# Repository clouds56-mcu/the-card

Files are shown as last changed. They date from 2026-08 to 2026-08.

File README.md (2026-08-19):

# The Card — E-Paper Smart Badge



**Website:** <https://clouds56-mcu.github.io/the-card/>

> An **ESP32-S3** based DIY/learning smart badge: e-paper wallpapers, Bluetooth, NFC, multi-button watch-style control, and on-board sensors, worn around the neck like an ID badge.

## 📋 Project Brief

| Item | Spec |
|---|---|
| **Positioning** | DIY / open learning platform (open-source, flashable, well-documented) |
| **MCU** | ESP32-S3-WROOM-1-N16R8 (16 MB Flash + 8 MB Octal PSRAM) |
| **Display** | 2.9" e-paper 296×128 (SSD1680, partial refresh / 4-gray) |
| **Wireless** | Bluetooth 5 LE (on-module) + NFC (ST25DV04KC dynamic tag, etched v0.2 antenna) |
| **Input** | 4× tactile buttons (up/down/select/menu, watch-style) |
| **Sensors** | 6-axis IMU (LSM6DSO) + Temp/Humidity (SHT40) |
| **Power** | 3.7 V Li-Po + USB-C charging + fuel gauge |
| **Wear** | Lanyard badge form factor |

## 📚 Documentation Index

| Doc | Description |
|---|---|
| [docs/architecture.md](docs/architecture.md) | System block diagram, subsystem design, **GPIO pin map** |
| [docs/bom.md](docs/bom.md) | Full BOM (with LCSC part #s / unit prices / links) + cost analysis |
| [docs/power-budget.md](docs/power-budget.md) | State-based power model + battery-life scenarios |
| [website/README.md](website/README.md) | Product site, hardware previews, and candidate release downloads |

## 💰 Key Takeaways

- **Component BOM (incl. panel + battery, excl. PCB/case):** ~$29 (1-off) / ~$21 (@100) / ~$18 (@1k)
- **Landed cost (incl. PCBA + case + assembly):** ~$40 (1-off) / ~$28 (@100) / ~$21 (@1k)
- **Cost driver:** e-paper panel (~$7, 33%) + MCU (~$4, 18%) + battery/IMU (~$2.5 each)
- **Battery life:** ~5.4 months theoretical for modeled daily use (1000 mAh), with ~4–5 months as a planning range; prototype measurement is pending
- **#1 power gotcha:** keep the WS2812 gated; the always-enabled SO-8 ST25DV and ME6211 dominate the revised ~0.16–0.17 mA sleep estimate

## 🚧 Optional Expansion (not in core BOM)

- Microphone (INMP441 / MSM261S) — voice interaction
- Ambient light (BH1750) — auto contrast
- Solar harvesting (paired with ST25DV's EH pin)
- Color e-paper (2.66" R/Y/B/W, slow 11 s refresh)

---

## 📄 License

This project is released under the **[MIT License](LICENSE)** — firmware, hardware designs, and documentation alike. Build it, modify it, ship it.

---

*Prices reflect 2026-08 LCSC / JLCPCB / Good Display market data and are for reference only — confirm at order time.*

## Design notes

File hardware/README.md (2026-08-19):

# hardware/ — Schematic & PCB (KiCad, code-first)

The electrical design of **the-card**, captured in code and emitted as both a
KiCad **schematic** (`.kicad_sch`) and a **netlist** (`.net`). KiCad 10 is
installed; the schematic opens in eeschema and is ERC-clean (0 errors).

```
hardware/
├── parts.yaml              # parts/procurement manifest, kept in sync with circuit.py
├── design_metadata.py      # sole project/design SemVer identity
├── pyproject.toml + uv.lock# uv project: skidl + easyeda2kicad (+ pypdf dev)
├── circuit.py              # the design in SKiDL (connectivity) -> the-card.net
├── gen_hierarchical_schematic.py # current deterministic A2 layout generator
├── gen_pcb.py              # deterministic placement, routing, planes, and keepouts
├── pcb_router.py           # board-specific fanout and deterministic maze routing
├── nfc_antenna.py          # v0.2 coil geometry and first-order RF model
├── verify_schematic.py     # compare every KiCad pin's peers with circuit.py
├── gen_schematic.py        # legacy flat-layout generator; not used currently
├── the-card.kicad_pro      # KiCad 10 project
├── the-card.kicad_sch      # GENERATED single-page A2 schematic
├── the-card.kicad_pcb      # GENERATED four-layer PCB layout
├── the-card.kicad_dru      # project DRC rules, including the NFC quiet area
├── sym-lib-table / fp-lib-table  # register our the-card + passives libraries
├── SCHEMATIC-GUIDE.md      # functional-region drawing and review notes
├── datasheets/             # archived datasheet PDFs + index
├── scripts/fetch_libs.sh   # regenerate libraries/ from LCSC#s in parts.yaml
├── scripts/normalize_libraries.py # reviewed corrections to fetched footprints
├── scripts/release_fabrication.py # checked Gerber/drill/BOM/placement release
├── scripts/export_design_review.py # portable CI schematic/PCB review exports
├── scripts/release_manifest.py # versioned release.json metadata + hashes
├── scripts/rasterize_svg.py # review PNGs from KiCad SVG plots
└── libraries/              # Reviewed 2D libs tracked; generated 3D models ignored
```

## One-time setup

```bash
cd hardware
uv sync                     # create .venv, install skidl + easyeda2kicad
./scripts/fetch_libs.sh     # fetch symbol/footprint/3D for every LCSC part
```

## Generate and verify

```bash
uv run python circuit.py
uv run python gen_hierarchical_schematic.py
uv run python verify_schematic.py
kicad-cli sch erc --severity-all --output /tmp/erc.json --format json the-card.kicad_sch
```

The verifier exports the complete KiCad schematic and compares both the peer
set of every component pin and every explicitly named net with the canonicalized
SKiDL circuit. The expected v0.2.0 result is 78 components and 292 component
pins with identical connectivity across 43 canonical named nets. KiCad ERC has 0
violations.

Generate the PCB layout with KiCad's bundled Python:

```bash
/Applications/KiCad/KiCad.app/Contents/Frameworks/\
Python.framework/Versions/3.9/bin/python3 gen_pcb.py
kicad-cli pcb drc --output /tmp/pcb-drc.json --format json the-card.kicad_pcb
```

The board is a portrait ID-1 outline (53.98 × 85.60 mm), four layers, and
0.8 mm thick. The display and controls are on the front; the ESP32, battery,
sensors, power circuitry, USB-C, and display connector are on the rear. The
generator encodes display, 603048 battery, ESP32 antenna, and NFC keepouts. The
NFC coil occupies a dedicated all-copper-layer RF quiet area: only `NFC_AC0`
and `NFC_AC1` antenna copper is allowed there, with no ground or power plane
beneath it. F.Cu and B.Cu carry local signals over ground pours, In1.Cu is the
primary ground plane, and In2.Cu is the primary 3V3 plane plus longer signal
routes. Ground stitching ties the pours together. The generated board is fully
routed and passes KiCad DRC with 0 violations and 0 unconnected items. Four
non-fabrication reference images are embedded beside the board in PCB Editor,
showing F.Cu, In1.Cu, In2.Cu, and B.Cu simultaneously without affecting plots.

## CI design review

For every CI run, `.github/workflows/ci.yml` publishes a short-lived
`design-review-<commit>` artifact after ERC and DRC pass. It contains the
schematic as PDF/SVG/PNG, a thumbnail, a multipage PCB PDF, and front, inner,
and mirrored back PCB PNGs. These files make schematic and layout changes easy
to inspect without KiCad; they are previews from one commit, not approved
fabrication outputs. The separate `kicad-reports` artifact retains the ERC and
DRC JSON reports, including reports from failed runs when available.

Run the manual `Hardware output` workflow when a complete candidate handoff is
needed. It rebuilds all release gates in the pinned KiCad environment and
uploads the fabrication, preview, assembly, reports, manifest, and checksums as
one 30-day Actions artifact. The workflow does not publish a GitHub Release or
mark the physical approval gates complete.

Build a manufacturing handoff into a new directory after generation:

```bash
uv run python scripts/release_fabrication.py \
  --output ../outputs/the-card-hardware-v0.2.0
```

`DESIGN_VERSION` in `design_metadata.py` is the sole maintained identity. It is
written in full to both KiCad title blocks and release metadata; the constrained
PCB silkscreen derives the matching major/minor mark (`HW 0.2`). Before 1.0, a
physical/electrical/mechanical PCB change advances the minor version, while an
artifact-only correction may advance the patch version. Never overwrite an
already published version. The first physically validated design can become
v1.0.0. The earlier v0.1.0 draft is retained only in Git history because it was
never ordered and contains the NFC issue corrected in v0.2.0.

The release command refuses to overwrite an existing directory or use a dirty
worktree. It runs the connectivity and canonical-net-name verifier, then
requires a clean full DRC, schematic parity check, and ERC. The output tree is:

```text
fabrication/       # Gerbers, PTH/NPTH drills, notes, fabrication-only ZIP
preview/           # schematic/PCB PDFs and PNGs, layer/drill plots, preview ZIP
assembly/
├── canonical/     # normalized BOM/placement CSV+JSON and assembly drawings
└── jlcpcb/        # upload-ready BOM and position CSVs
reports/           # ERC, DRC/parity, and drill reports
release.json       # release identity, provenance, validation, pending approval
SHA256SUMS         # hashes for every artifact and release.json
```

Pass `--include-3d` only when all ignored supplier 3D models referenced by the
board are present and reviewed. Without it, the release remains complete for
fabrication and assembly and uses 2D previews generated from tracked design
files. The internal assembly BOM reports unresolved sourcing explicitly; a
clean board does not imply that every row is ready for a turnkey PCBA order. See
[`FABRICATION.md`](FABRICATION.md) before sending any files to a board house.

`assembly/jlcpcb/bom.csv` follows JLC's eight-column
`Comment, Description, Designator, Footprint, LibRef, Pins, Quantity, JLCPCB Part #`
format. Exact LCSC/JLC codes are written to `JLCPCB Part #` when assigned.
`assembly/jlcpcb/positions.csv` is the matching millimetre CPL with
`Designator, Mid X, Mid Y, Rotation, Layer` and normalized `Top`/`Bottom`
layer names.

Open the schematic:
```bash
/Applications/KiCad/KiCad.app/Contents/MacOS/eeschema the-card.kicad_sch
```

> `gen_hierarchical_schematic.py` is retained under its original filename, but it
> now emits one A2 sheet. It overwrites `the-card.kicad_sch`; put durable layout
> changes into its placement and region-offset tables so regeneration stays
> deterministic. `gen_schematic.py` is the previous flat A1 generator and is
> retained only as a reference.

## How it fits together

`parts.yaml` holds procurement and part data. Its `lcsc_parts` section drives
EasyEDA library fetching, while `assembly_parts` records exact BOM selections
that reuse existing project or KiCad symbols and footprints. An
`assembly_parts` entry with the same reference as an `lcsc_parts` entry
overrides only the procurement selection, allowing a verified pin-compatible
replacement to keep the existing symbol and footprint. `fetch_libs.sh`
builds the two KiCad libraries, while `circuit.py` defines electrical
connectivity and emits `the-card.net`. The layout generator imports that circuit
and changes only its presentation: one A2 page containing Power/USB, MCU,
NFC/sensors, e-paper, and UI
regions. For an electrical change, update `circuit.py`, regenerate the netlist and
schematic, then run `verify_schematic.py` before accepting the result. See
[`FABRICATION.md`](FABRICATION.md) for stackup, ordering, and assembly checks.

Every resistor and capacitor also receives hidden `Related To` and `Function`
properties from `circuit.py`. The single-page schematic shows compact functional
callouts, while KiCad properties and the internal assembly BOM retain the exact
per-reference annotations without crowding the drawing. The layout keeps support
passives beside their related blocks and emits explicit dots at true wire
junctions; visually crossing wires without a dot are not connected.

## Verification status (done)

The originally flagged sections were checked against datasheets (see
`../PROGRESS.md` §7 and the full pinout cross-check). The bare panel's required
SSD1680 booster, 25 V pump capacitors, and 50 V rail bypass network are now
present on the host PCB. Residual
PCB-layout items are:

- **ST25DV04KC antenna** — design v0.2.0 uses a nine-turn, 0.20 mm F.Cu spiral in the
  front-left strip, with a dedicated quiet area on all four copper layers. The
  ST square-equivalent heuristic gives about 4.52 µH; an NXP rectangular-coil
  cross-check brackets about 3.19–3.98 µH and implies roughly 6.1–14.7 pF of
  nominal added capacitance before stray/assembly loading. C29 therefore accepts
  0–22 pF C0G/NP0, but remains unpopulated until measurement. Verify resonance,
  Q, and multi-phone read/write range in the final enclosure; treat more than
  about 15–18 pF, poor Q, or inadequate range as an antenna-respin signal.
- **Display FPC** — J2 is now the verified single-row Hirose
  FH12-24S-0.5SH(55): 24 positions, 0.5 mm pitch, bottom contact, for a 0.30 mm
  FPC. The project footprint numbers its two hold-down tabs 25 and 26 so both
  are tied to ground by the schematic. Rear silkscreen marks pin 1; confirm the
  folded panel orientation with a paper or physical mock-up before ordering.
- **JST-PH battery polarity** — rear silkscreen marks `BAT+` and `BAT-`, but the
  selected pack's cable must still be verified before plugging it in.

The DW01A/HXY 8205A protection stage has been checked against both datasheets:
R9=100 Ω, R10=1 kΩ, DOUT drives G1 on the cell-negative side, and COUT drives
G2 on the pack-negative side.

## Gotchas

- **easyeda2kicad 1.0.1:** `--output` must be **absolute** with
  `--project-relative` (relative paths crash). `fetch_libs.sh` handles this.
- **EasyEDA API 403:** rate-limits after a big batch — re-run in a few minutes.
- **SKiDL reports pin Y inverted** vs KiCad (math y-up vs KiCad y-down); the
  layout generator handles KiCad's screen-coordinate rotations explicitly.
- **ESP32-S3-WROOM-1-N16R8** uses GPIO33–37 for its Octal PSRAM;
  `circuit.py` leaves GPIO35–37 unconnected and uses GPIO16 for `EPD_PWR_EN`.
- The ST25DV SO-8 GPO is open-drain. Design v0.2.0 adds its required 10 kΩ pull-up R17
  and routes `NFC_IRQ` to GPIO21; GPIO3 is deliberately unused because it is a
  strap-sensitive pin.
- The generator sets embedded part pins to `passive` because several EasyEDA
  symbols have incorrect electrical types. `verify_schematic.py` independently
  checks actual connectivity rather than relying on those types.

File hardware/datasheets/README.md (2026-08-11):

# Datasheets

Reference manuals for the-card's components — **all archived locally as PDF** so
the design is reviewable offline and survives link-rot. PDFs are committed on
purpose: manufacturer pages and URLs change or disappear, and for a hardware
project an archived datasheet is part of the design record.

## Local archive

| Ref | Part | LCSC | File | Source |
|---|---|---|---|---|
| U1 | ESP32-S3-WROOM-1 (module) | C2913202 | `ESP32-S3-WROOM-1_Espressif.pdf` | Espressif |
| U1 | ESP32-S3 (chip) | — | `ESP32-S3_Espressif.pdf` | Espressif |
| U2 | ST25DV04KC | C5221752 | `ST25DV04KC_ST.pdf` | ST (Farnell mirror) |
| U3 | LSM6DSO | C2655100 | `LSM6DSO_ST.pdf` | ST (LCSC) |
| U4 | SHT40 | C7461849 | `SHT40_Sensirion.pdf` | Sensirion (SparkFun CDN) |
| U5 | MAX17048 | C2682616 | `MAX17048_Maxim.pdf` | Maxim/ADI (LCSC) |
| U6 | TP4056 | C382139 | `TP4056.pdf` | TPOWER (LCSC wmsc) |
| U7 | DW01A | C18164398 | `DW01A_Fortune.pdf` | Fortune Semiconductor |
| U8 | HXY 8205A | C5148694 | [HXY datasheet](https://www.lcsc.com/datasheet/C5148694.pdf); `FS8205A_Fortune.pdf` is the pin-compatible symbol-template reference | HXY MOSFET / Fortune Semiconductor |
| U9 | ME6211C33 | C82942 | `ME6211_Microne.pdf` | MICRONE (LCSC) |
| U10 | USBLC6-2SC6 | C7519 | `USBLC6-2_ST.pdf` | ST (LCSC) |
| Q1, Q2 | SI2301 | C10487 | `SI2301_Vishay.pdf` | Vishay (LCSC) |
| D1 | WS2812B-Mini | C527089 | `WS2812B-Mini_Worldsemi.pdf` | Worldsemi (LCSC) |
| J1 | TYPE-C-31-M-12 | C165948 | `TYPE-C-31-M-12.pdf` | LCSC |
| SW1–4 | TS-1187A | C318884 | `TS-1187A.pdf` | LCSC |
| J2 / panel | GDEY029T94 | — (distributor) | `GDEY029T94_GoodDisplay.pdf` + `GDEY029T94_extracted.md` | Good Display |
| — | SSD1680 (e-ink driver IC) | — | `SSD1680_SolomonSystech.pdf` | Solomon Systech |

LCSC product page pattern: `https://www.lcsc.com/product-detail/C<LCSC>.html`

## Notes

- `st.com` and `espressif.com` block scripted downloads, so those were fetched
  via mirrors (LCSC, Farnell, DigiKey, SparkFun/Adafruit CDNs) that allow it.
- The GDEY029T94 has a text extraction (`GDEY029T94_extracted.md`) for quick
  grep of the pin table — the §5 pin assignment was used to verify `circuit.py`.
- Battery (3.7 V 1000 mAh, 603048) and lanyard hardware have no part datasheet.
- **Re-verify the revision before tape-out.** Datasheets get reissued (e.g.
  GDEY029T94 `24.10.22`) and pinouts/footprints can shift between revs.

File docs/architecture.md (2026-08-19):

# System Architecture

## 1. Block Diagram

```
                           ┌─────────────────────────────────────────────┐
                           │              ESP32-S3-WROOM-1-N16R8         │
                           │  (Dual-core 240MHz · 16MB Flash · 8MB PSRAM)│
                           │                                             │
   USB-C ──┬─ ESD ── D+/D-─┤  USB-Serial-JTAG (native USB, no CH340)     │
   5V  ────┤               │                                             │
           │               │  SPI  ──► [E-ink SSD1680 2.9" 296×128]       │
   TP4056 ◄─┘ charge        │  I2C0 ─► { ST25DV04KC · LSM6DSO · SHT40     │
   DW01+MOS ◄─ protection   │             · MAX17048 }                    │
           │                │  GPIO ► 4× Tactile Buttons (deep-sleep wake)│
   Li-ion 3.7V              │  GPIO ─► WS2812 RGB (via MOSFET power gate)│
   1000mAh ─┬─ LDO 3.3V ───►│                                             │
           │                │  IRQ  ◄─ NFC GPO / IMU INT                  │
           └────────────────┤  ADC  ◄─ VBATT divider (MAX17048 primary)   │
                            └─────────────────────────────────────────────┘
```

## 2. Subsystem Design

### 2.1 MCU — why ESP32-S3

| Candidate | Trade-off | Verdict |
|---|---|---|
| **ESP32-S3-WROOM-1-N16R8** ✅ | 16 MB Flash for OTA and assets + 8 MB Octal PSRAM for image/UI headroom, native USB, strong availability | **Selected** |
| N8R2 (8 MB Flash, 2 MB Quad PSRAM) | Sufficient for the current framebuffer, but offers less OTA/image headroom without a consistent sourcing advantage | Alt (minimum memory) |
| N4 (4 MB, no PSRAM) | Frame buffer squeezes SRAM, large-image refresh struggles | Alt (max savings) |
| S3-MINI-1 | Smaller but dense routing, less DIY-friendly | No |
| Bare die S3FN8 | Requires own RF + Flash routing, not for a learning platform | No |

- **N16R8 over N8R2:** the footprint is identical, current sourcing is at least
  as strong, and the extra memory simplifies dual-slot OTA, image decoding,
  fonts, and future UI work. Firmware must select 16 MB Quad flash and 8 MB
  Octal PSRAM.
- N16R8's recommended ambient range is −40 to +65 °C, versus +85 °C for N8R2;
  +65 °C is acceptable for this consumer wearable, but not an industrial-hot
  environment.
- On-module PCB antenna → **no RF design required**, DIY-friendly.

### 2.2 Display Subsystem

- **Main panel:** 2.9" 296×128 monochrome e-paper (GDEY029T94, SSD1680 controller)
  - 4-wire SPI, supports **partial refresh 0.3 s / full refresh 1.5 s** / 4-gray
  - Bistable: **zero power for a static image** — the core of badge battery life
  - Outline 79×36.7 mm — exactly standard badge aspect ratio
- Routing: 24-pin 0.5 mm FPC flip connector for easy panel swap
- Host support: 47 µH SSD1680 boost stage, 30 V MOSFET/Schottky diodes, and
  25 V-rated pump/HV bypass capacitors per the panel reference design
- **Note:** SSD1680 has no power-enable pin; Q2 cuts the panel VCI/booster input

### 2.3 Wireless Subsystem

| Channel | Chip | Role |
|---|---|---|
| Bluetooth 5 LE | ESP32-S3 on-module | Phone app pushes wallpapers, config, OTA |
| NFC 13.56 MHz | **ST25DV04KC** (4 Kbit dynamic tag) | Phone tap reads badge info / vCard / URL; MCU rewrites tag content anytime over I2C |

**Why ST25DV04KC over NXP NTAG I2C Plus:**
- ✅ Dynamic tag memory can be updated by the MCU over I²C
- ✅ **GPO wake pin:** phone proximity triggers an MCU interrupt (enables "tap to check-in")
- ✅ Cheaper (~$0.44 @100 vs NT3H2211 ~$0.7)
- ⚠️ Type 5 (ISO15693); modern phones support NDEF fine; only very old devices are slightly less compatible than Type 2

The IC supports energy harvesting, but `V_EH` is intentionally left unconnected
in the current design to keep the power architecture simple.

Design v0.2.0 connects the ST25DV's open-drain GPO through mandatory 10 kΩ pull-up R17
to `NFC_IRQ` on RTC-capable GPIO21; GPIO3 is no longer used because it is a
strap-sensitive pin. The antenna uses distinct `NFC_AC0`/`NFC_AC1` nets, a
nine-turn 0.20 mm F.Cu etched coil (L2), and an all-four-copper-layer RF quiet
area. DNP C29 accepts 0–22 pF C0G/NP0 only after measurement shows how far the
assembled antenna sits above 13.56 MHz. Parallel capacitance can lower a high
resonance, but it cannot correct an antenna that already resonates below the
target.

### 2.4 Sensor Subsystem

| Sensor | Model | Purpose | Low power |
|---|---|---|---|
| 6-axis IMU | **LSM6DSO** | Flip-to-wake, step count, raise-to-wake, gestures | LP 0.012 mA |
| Temp/Humidity | **SHT40** | Environment (shown in a screen corner) | Standby 0.4 µA |

- Both sensors share **I2C0 bus** (multiplexed with NFC + fuel gauge)
- During deep sleep the IMU stays in low-power mode and wakes the MCU via its INT pin

### 2.5 Power Subsystem

```
 USB-C 5V ──► TP4056 (~500mA CC) ──► [DW01 + FS8205A protection] ──► BAT+ 3.0~4.2V
                                                                  │
                                                  ME6211 LDO 3.3V ◄┘
                                                       │ 3.3V system rail
                              ┌────────────────────────┼──────────────┐
                              │                        │              │
                     ESP32-S3 + sensors          Load Switch ──► status LED
                        (always powered)          (P-MOSFET, cut in deep sleep)
```

- **Charge:** TP4056 (~500 mA CC/CV from 2.2 kΩ RPROG, thermal regulation)
- **Protection:** DW01A (over-charge / over-discharge / short) + FS8205A dual MOSFET
- **Regulation:** ME6211C33 (3.3 V, 60 µA typical enabled supply current, 500 mA)
- **Fuel gauge:** MAX17048 (ModelGauge algorithm, 3 µA, I2C, no sense resistor) → accurate % on screen
- **Key:** the WS2812 sits on a **switchable branch rail** (P-MOSFET), fully cut
  in deep sleep. The sensors share always-on +3V3 with the I²C pullups so the bus
  cannot back-power an unpowered sensor.

### 2.6 Input Subsystem

- **4 tactile buttons** (watch-style layout):
  - `UP` / `DOWN`: browse wallpaper list
  - `SELECT`: confirm / set full-screen wallpaper
  - `MENU`: enter settings / Bluetooth / battery / sensor page
- All on GPIO with internal pull-ups, **support ext0/ext1 + button-combo wake from deep sleep**
- Hardware RC debounce + software debounce

---

## 3. GPIO Pin Map (ESP32-S3-WROOM-1-N16R8)

> Module memory occupies GPIO26–37; GPIO33–37 are specifically unavailable
> because N16R8 uses Octal PSRAM. GPIO19/20 carry USB, and GPIO0/3/45/46 are
> strap-sensitive pins that must be used carefully.

| GPIO | Function | Dir | Notes |
|---|---|---|---|
| **—— E-ink SPI (FSPI) ——** | | | |
| GPIO11 | EPD_BUSY | IN | Panel busy |
| GPIO12 | EPD_CS | OUT | Chip select |
| GPIO13 | EPD_DC | OUT | Data/command |
| GPIO14 | EPD_RST | OUT | Reset |
| GPIO10 | EPD_SCLK | OUT | SPI clock |
| GPIO9  | EPD_SDA(DIN) | OUT | SPI MOSI |
| **—— I2C0 (sensors + NFC + fuel gauge) ——** | | | |
| GPIO8  | I2C_SCL | OUT/OD | Bus clock |
| GPIO18 | I2C_SDA | I/O/OD | Bus data |
| **—— Interrupt inputs ——** | | | |
| GPIO21 | NFC_IRQ | IN | ST25DV open-drain GPO wake; external 10 kΩ pull-up R17 |
| GPIO2  | IMU_INT | IN | LSM6DSO motion/flip interrupt |
| GPIO15 | CHRG_STAT | IN | TP4056 charge status |
| **—— Buttons (deep-sleep wake, internal pull-up) ——** | | | |
| GPIO4  | BTN_UP | IN | Up |
| GPIO5  | BTN_DOWN | IN | Down |
| GPIO6  | BTN_SEL | IN | Select |
| GPIO7  | BTN_MENU | IN | Menu |
| **—— Outputs / peripherals ——** | | | |
| GPIO47 | PWR_AUX | OUT | Branch-rail P-MOS gate (cuts the status LED) |
| GPIO16 | EPD_PWR_EN | OUT | E-paper VCI/booster P-MOS gate |
| GPIO48 | LED_DIN | OUT | WS2812 data (GPIO48 is the classic S3 RGB pin, on branch rail) |
| **—— USB (native, fixed) ——** | | | |
| GPIO19 | USB_D- | I/O | Programming + power |
| GPIO20 | USB_D+ | I/O | Programming + power |
| **—— Battery monitor ——** | | | |
| GPIO1  | VBATT_DIV | IN(ADC1_CH0) | Divider sample (backup; MAX17048 is primary) |
| **—— Reserved expansion ——** | | | |
| GPIO3 | Reserved strap | — | Left unconnected; do not use for NFC wake |
| GPIO17/38–46 | Expansion | — | Unconnected; GPIO18 is used by I2C and GPIO35–37 by Octal PSRAM |

> ⚠️ On ESP32-S3, ADC2 is unavailable while WiFi is on, so battery-voltage sampling must use **ADC1 (GPIO1–10)**. The table above already respects this.

---

## 4. Key Design Decisions

| # | Decision | Rationale |
|---|---|---|
| 1 | WROOM module, not bare die | No RF design, DIY-friendly, easier certification |
| 2 | N16R8 (16 MB Flash + 8 MB Octal PSRAM) | Better OTA/image headroom and current sourcing with no PCB change |
| 3 | NFC uses dynamic tag ST25DV04KC with a tunable etched coil | MCU rewrite + pulled-up GPIO21 wake; `V_EH` is deferred; physical resonance/range testing is required |
| 4 | Native USB, no CH340 | Saves a chip, space, and cost |
| 5 | Gate the WS2812, keep I²C sensors on +3V3 | Removes LED leakage without I²C back-power paths |
| 6 | 2.9" monochrome e-paper (not color) | Color is slow (11 s) and pricier; mono partial refresh 0.3 s feels great |
| 7 | MAX17048 fuel gauge (not a plain divider) | Li-ion discharge curve is non-linear; ModelGauge gives an accurate on-screen % |

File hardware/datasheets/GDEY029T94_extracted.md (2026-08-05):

# GDEY029T94

> Source: https://www.laskakit.cz/user/related_files/gdey029t94.pdf
> Pages: 37
> Author: DALIAN GOOD DISPLAY CO.,LTD.

---

2.9 inch E-pa per Display Series GDE Y029T94 Dalian Good Display Co., Ltd. GOOD DISPLAY

<!-- Page 2 -->

Product Specifications Customer Standard Description 2.9 ” E -PAPER DISPLAY Model Name GDE Y029T94 Date 20 21 /0 3 / 15 Revision 1 .0 Design Engineering Approval Check Design Zhongnan Building, No.18, Zhonghua West ST,Ganjingzi DST,Dalian,CHINA Tel: +86-41 1 -84619565 Email: info@good-display.com Website: www. good- display.co m GDEY029T94 www.good-display.com 2 37 2.9 inch Series GOOD DISPLAY

<!-- Page 3 -->

REVISION HISTORY Rev Date Item Page Remark 1.0 MAR.15.2021 New Creation ALL GDEY029T94 www.good-display.com 3 37 2.9 inch Series GOOD DISPLAY

<!-- Page 4 -->

CONTENTS 1. 2. 3. 4. 5. 6. 7. 8. 9. 10. Over View.............................................................................. Features .............................................................................. Mechanical Specification.......................................................... Mechanical Drawing of EPD Module............................................ Input/output Pin Assignment.................................................... Electrical Characteristics.......................................................... 6.1 Absolute Maximum Rating.................................................. 6.2 Panel DC Characteristics..................................................... 6. 3 Panel AC Characteristics..................................................... 6. 3 .1 MCU Interface Selection............................................... ... 6. 3 .2 MCU Serial Interface (4-wire SPI).................................. ... 6. 3 .3 MCU Serial Interface (3-wire SPI).................................. ... 6. 3 .4 Interface Timing......................................................... .... Command Table...................................................................... Optical Specification................................................................ Handling, Safety, and Environment Requirements....................... Reliability Test........................................................................ 6 6 6 7 8 9 9 10 11 11 11 1 2 1 3 1 4 2 5 26 2 7 GDEY029T94 www.good-display.com 4 37 2.9 inch Series GOOD DISPLAY

<!-- Page 5 -->

11. 12. 13. 14. 15. 16. 17. Block Diagram........................................................................ Reference Circuit ............................... ..................................... Matched Development Kit......................................................... Typical Operating Sequence...................................................... 14.1 Normal Operation Flow..................................................... Inspection condition................................................................ 15.1 Environment................................................................... 15.2 Illuminance..................................................................... 15.3 Inspect method............................................................... 15.4 Display area.................................................................... 15.5 Inspection standard......................................................... 15.5.1 Electric inspection standard........................................ 15.5.2 Appearance inspection standard.................................. Packaging.............................................................................. Precautions............................................................................ 2 8 2 9 30 31 31 32 3 2 3 2 3 2 3 2 3 3 3 3 3 4 3 6 3 7 GDEY029T94 www.good-display.com 5 37 2.9 inch Series GOOD DISPLAY

<!-- Page 6 -->

1. Over View GDEY029T94 is an Active Matrix Electrophoretic Display (AM EPD), with interface and a reference system design. The display is capable to display images at 1-bit white, black full display capabilities. The 2.9 inch active area contains 296×128 pixels. The module is a TFT-array driving electrophoresis display, with integrated circuits including gate driver, source driver, MCU interface, timing controller, oscillator, DC-DC, SRAM, LUT, VCOM. Module can be used in portable electronic devices, such as Electronic Shelf Label (ESL) System. 2.Features 296×128 pixels display High cntrast High reflectance Ultra wide viewing angle Ultra low power consumption Pure reflective mode Bi-stable display Commercial temperature range Landscape portrait modes Hard-coat antiglare display surface Ultra Low current deep sleep mode On chip display RAM Waveform can stored in On-chip OTP or written by MCU Serial peripheral interface available On-chip oscillator On-chip booster and regulator control for generating VCOM, Gate and Source driving voltage I2C signal master interface to read external temperature sensor Built-in temperature sensor Parameter Specifications Unit Remark Screen Size 2.9 Inch Display Resolution 296 (H)×128(V) Pixel Dpi:125 Active Area 29.056(H)×66.896(V) mm Pixel Pitch 0.227×0.226 mm Pixel Configuration Rectangle Outline Dimension 36.7(H)×79.0(V) ×1.2(D) mm Weight 5.5±0.5 g 3.Mechanical Specifications GDEY029T94 www.good-display.com 6 37 2.9 inch Series GOOD DISPLAY

<!-- Page 7 -->

4. Mechanical Drawing of EPD module DALIAN GOOD DISPLAY CO.,LTD GDEY029T94 www.good-display.com 7 37 2.9 inch Series GOOD DISPLAY

<!-- Page 8 -->

5. Input /Output Pin Assignment No. Name I/O Description Remark 1 NC Do not connect with other NC pins Keep Open 2 GDR O N-Channel MOSFET Gate Drive Control 3 RESE I Current Sense Input for the Control Loop 4 NC NC Do not connect with other NC pins Keep Open 5 VSH2 C Positive Source driving voltage(Red) 6 TSCL O I 2 C Interface to digital temperature sensor Clock pin 7 TSDA I/O I 2 C Interface to digital temperature sensor Data pin 8 BS1 I Bus Interface selection pin Note 5-5 9 BUSY O Busy state output pin Note 5-4 10 RES# I Reset signal input. Active Low. Note 5-3 11 D/C# I Data /Command control pin Note 5-2 12 CS# I Chip select input pin Note 5-1 13 SCL I Serial Clock pin (SPI) 14 SDA I/O Serial Data pin (SPI) 15 VDDIO P Power Supply for interface logic pins It should be connected with VCI 16 VCI P Power Supply for the chip 17 VSS P Ground 18 VDD C Core logic power pin VDD can be regulated internally from VCI. A capacitor should be connected between VDD and VSS 19 VPP P FOR TEST 20 VSH1 C Positive Source driving voltage 21 VGH C Power Supply pin for Positive Gate driving voltage and VSH1 22 VSL C Negative Source driving voltage 23 VGL C Power Supply pin for Negative Gate driving voltage VCOM and VSL 24 VCOM C VCOM driving voltage GDEY029T94 www.good-display.com 8 37 2.9 inch Series GOOD DISPLAY

<!-- Page 9 -->

I = Input Pin, O =Output Pin, I/O = Bi-directional Pin (Input/output), P = Power Pin, C = Capacitor Pin Note 5-1: This pin (CS#) is the chip select input connecting to the MCU. The chip is enabled for MCU communication only when CS# is pulled LOW. Note 5-2: This pin is (D/C#) Data/Command control pin connecting to the MCU in 4-wire SPI mode. When the pin is pulled HIGH, the data at SDA will be interpreted as data. When the pin is pulled LOW, the data at SDA will be interpreted as command. Note 5-3: This pin (RES#) is reset signal input. The Reset is active low. Note 5-4: This pin is Busy state output pin. When Busy is High, the operation of chip should not be interrupted, command should not be sent. The chip would put Busy pin High when –Outputting display waveform -Communicating with digital temperature sensor Note 5-5: Bus interface selection pin 6. Electrical Characteristics 6.1 Absolute Maximum Rating Parameter Symbol Rating Unit Logic supply voltage VCI -0.5 to +4.0 V Logic Input voltage VIN -0.5 to VCI +0.5 V Logic Output voltage VOUT -0.5 to VCI +0.5 V Operating Temp range TOPR 0 to +50 º C Storage Temp range TSTG -25 to+70 º C Optimal Storage Temp TSTGo 23±2 º C Optimal Storage Humidity HSTGo 55±10 %RH Note: Maximum ratings are those values beyond which damages to the device may occur. Functional operation should be restricted to the limits in the Panel DC Characteristics tables. BS1 State MCU Interface L 4-lines serial peripheral interface(SPI) - 8 bits SPI H 3- lines serial peripheral interface(SPI) - 9 bits SPI GDEY029T94 www.good-display.com 9 37 2.9 inch Series GOOD DISPLAY 6.2 Panel DC Characteristics The following specifications apply for: VSS=0V, VCI=3.0V, TOPR =25ºC .

<!-- Page 10 -->

1. The typical power is measured with following transition from horizontal 2 scale pattern to vertical 2 scale pattern. 2.The deep sleep power is the consumed power when the panel controller is in deep sleep mode. 3.The listed electrical/optical characteristics are only guaranteed under the controller & waveform provided by GOOD DISPLAY. GDEY029T94 www.good-display.com 10 37 2.9 inch Series Parameter Symbol Conditions Applica ble pin Min. Typ. Max Units Single ground V SS - - 0 - V Logic supply voltage V CI - VCI 2.2 3.0 3.7 V Core logic voltage V DD VDD 1.7 1.8 1.9 V High level input voltage V IH - - IOH = - 100uA -- -- -- -- -- 0.8 V CI -- -- 9 - 0.2 V CI V Low level input voltage V IL - 0.9 VCI V High level output voltage V OH - 0.1 V CI V Low level output voltage V OL IOL = 100uA -- -- -- - V Typical power P TYP V CI =3.0V -- -- -- mW Deep sleep mode P STPY V CI =3.0V 0.003 mW Typical operating current Iopr_ V CI V CI =3.0V 3.0 mA Full update time -- - 25 ºC 3 sec Fast update time 25 ºC 1.5 sec Partial refresh time 25 ºC 0.3 sec Sleep mode current Islp_V CI DC/DC off No clock Ram data retain No input load - - 20 uA Deep sleep mode current Idslp_ V CI DC/DC off No clock No input load Ram data not retain - - 1 5 uA GOOD DISPLAY Notes: 1) Refresh time: the time it takes for the whole process from the screen change to the screen stabilization. 2) The difference between different refresh methods: Full refresh: The screen will flicker several times during the refresh process; Fast Refresh: The screen will flash once during the refresh process; Partial refresh: The screen does not flicker during the refresh process. During the fast refresh or partial refresh of the electronic paper, it is recommended to add a full-screen refresh after 5 consecutive operations to reduce the accumulation of afterimages on the screen.

<!-- Page 11 -->

6.3 Panel AC Characteristics 6.3.1 MCU Interface Selection The pin assignment at different interface mode is summarized in Table 6-4-1. Different MCU mode can be set by hardware selection on BS1 pins. The display panel only supports 4-wire SPI or 3-wire SPI interface mode. Pin Name Data/Command Interface Control Signal Bus interface SDA SCL CS# D/C# RES# BS1=L 4-wire SPI SDA SCL CS# D/C# RES# BS1=H 3-wire SPI SDA SCL CS# L RES# 6.3.2 MCU Serial Interface (4-wire SPI) The serial interface consists of serial clock SCL, serial data SDA, D/C#, CS#. This interface supports Write mode and Read mode. Function CS# D/C# SCL Write command L L ↑ Write data L H ↑ Note: ↑ stands for rising edge of signal In the write mode SDA is shifted into an 8-bit shift register on every rising edge of SCL in the order of D7, D6, ... D0. The level of D/C# should be kept over the whole byte . The data byte in the shift register is written to the Graphic Display Data RAM /Data Byte register or command Byte register according to D/C# pin. GDEY029T94 www.good-display.com 11 37 2.9 inch Series GOOD DISPLAY

<!-- Page 12 -->

6.3.3 MCU Serial Interface (3-wire SPI) The 3-wire serial interface consists of serial clock SCL, serial data SDA and CS#. This interface also supports Write mode and Read mode. The operation is similar to 4-wire serial interface while D/C# pin is not used. There are altogether 9-bits will be shifted into the shift register on every ninth clock in sequence: D/C# bit, D7 to D0 bit. The D/C# bit (first bit of the sequential data) will determine the following data byte in the shift register is written to the Display Data RAM (D/C# bit = 1) or the command register (D/C# bit = 0). Function CS# D/C# SCL Write command L Tie ↑ Write data L Tie ↑ Note ：↑ stands for rising edge of signal In the Read mode: 1. After driving CS# to low, MCU need to define the register to be read. 2. D/C=0 is shifted thru SDA with one rising edge of SCL 3. SDA is shifted into an 8-bit shift register on every rising edge of SCL in the order of D7, D6, ... D0. 4. D/C=1 is shifted thru SDA with one rising edge of SCL 5. SDA is shifted out an 8-bit data on every falling edge of SCL in the order of D7, D6, … D0. 6. Depending on register type, more than 1 byte can be read out. After all byte are read, CS# need to drive to high to stop the read operation. GDEY029T94 www.good-display.com 12 37 2.9 inch Series GOOD DISPLAY

<!-- Page 13 -->

6.3.4 Interface Timing The following specifications apply for: VSS=0V, VCI=3.0V, TOPR =25ºC. GDEY029T94 www.good-display.com 13 37 2.9 inch Series GOOD DISPLAY

<!-- Page 14 -->

7. Command Table GDEY029T94 www.good-display.com 14 37 2.9 inch Series GOOD DISPLAY

<!-- Page 15 -->

GDEY029T94 www.good-display.com 15 37 2.9 inch Series GOOD DISPLAY

<!-- Page 16 -->

GDEY029T94 www.good-display.com 16 37 2.9 inch Series GOOD DISPLAY

<!-- Page 17 -->

GDEY029T94 www.good-display.com 17 37 2.9 inch Series GOOD DISPLAY

<!-- Page 18 -->

GDEY029T94 www.good-display.com 18 37 2.9 inch Series GOOD DISPLAY

<!-- Page 19 -->

GDEY029T94 www.good-display.com 19 37 2.9 inch Series GOOD DISPLAY

<!-- Page 20 -->

GDEY029T94 www.good-display.com 20 37 2.9 inch Series GOOD DISPLAY

<!-- Page 21 -->

GDEY029T94 www.good-display.com 21 37 2.9 inch Series GOOD DISPLAY

<!-- Page 22 -->

GDEY029T94 www.good-display.com 22 37 2.9 inch Series GOOD DISPLAY

<!-- Page 23 -->

GDEY029T94 www.good-display.com 23 37 2.9 inch Series GOOD DISPLAY

<!-- Page 24 -->

GDEY029T94 www.good-display.com 24 37 2.9 inch Series GOOD DISPLAY

<!-- Page 25 -->

8.Optical Specifications Measurements are made with that the illumination is under an angle of 45 degree, the detection is perpendicular unless otherwise specified Symbol Parameter Conditions Min Typ. Max Units Notes R White Reflectivity White 30 35 - % 8-1 CR Contrast Ratio Indoor 8:1 - 8-2 GN 2Grey Level - DS+(WS-DS)*n(m-1) 8-3 T update Image update time at 25 °C 3 - sec Life Topr 1000000times or 5years Notes: 8-1. Luminance meter: Eye-One Pro Spectrophotometer. 8-2. CR=Surface Reflectance with all white pixel/Surface Reflectance with all black pixels. 8-3 WS: White state, DS: Dark state GDEY029T94 www.good-display.com 25 37 2.9 inch Series GOOD DISPLAY

<!-- Page 26 -->

9. Handling, Safety and Environment Requirements Warning The display glass may break when it is dropped or bumped on a hard surface. Handle with care. Should the display break, do not touch the electrophoretic material. In case of contact with electrophoretic material, wash with water and soap. Caution The display module should not be exposed to harmful gases, such as acid and alkali gases, which corrode electronic components. Disassembling the display module. Disassembling the display module can cause permanent damage and invalidates the warranty agreements. Observe general precautions that are common to handling delicate electronic components. The glass can break and front surfaces can easily be damaged. Moreover the display is sensitive to static electricity and other rough environmental conditions. Data sheet status Product specification This data sheet contains final product specifications. Limiting values Limiting values given are in accordance with the Absolute Maximum Rating System (IEC 134).Stress above one or more of the limiting values may cause permanent damage to the device. These are stress ratings only and operation of the device at these or at any other conditions above those given in the Characteristics sections of the specification is not implied. Exposure to limiting values for extended periods may affect device reliability. Application information Where application information is given, it is advisory and does not form part of the specification. GDEY029T94 www.good-display.com 26 37 2.9 inch Series GOOD DISPLAY

<!-- Page 27 -->

10.Reliability test NO Test items Test condition 1 Low-Temperature Storage T = -25°C, 240 h Test in white pattern 2 High-Temperature Storage T=70 º C ， RH=40% ， 240h Test in white pattern 3 High-Temperature Operation T=50 º C ， RH=35% ， 240h 4 Low-Temperature Operation 0 º C ， 240h 5 High-Temperature, High-Humidity Operation T=40 º C ， RH=80% ， 240h 6 High Temperature, High Humidity Storage T=50 º C ， RH=80%, 240h Test in white pattern 7 Temperature Cycle 1 cycle:[-25 ° C 30min] → [+70 ° C 30 min] : 50 cycles Test in white pattern 8 UV exposure Resistance 765W/m² for 168hrs,40 °C Test in white pattern 9 ESD Gun Air+/-15KV;Contact+/-8KV (Test finished product shell, not display only) Air+/-8KV;Contact+/-6KV (Naked EPD display, no including IC and FPC area) Air+/-4KV;Contact+/-2KV (Naked EPD display, including IC and FPC area) Note: Put in normal temperature for 1hour after test finished, display performance is ok. GDEY029T94 www.good-display.com 27 37 2.9 inch Series GOOD DISPLAY

<!-- Page 28 -->

11. Block Diagram GDEY029T94 www.good-display.com 28 37 2.9 inch Series GOOD DISPLAY

<!-- Page 29 -->

12. Reference Circuit GDEY029T94 www.good-display.com 29 37 2.9 inch Series GOOD DISPLAY

<!-- Page 30 -->

13. Matched Development Kit Our Development Kit designed for SPI E-paper Display aims to help users to learn how to use E-paper Display more easily. It can refresh black- white E-paper Display and three-color (black, white and red/Yellow) Good Display ‘s E-paper Display. And it is also added the functions of USB serial port, Raspberry Pi and LED indicator light ect. DESPI Development Kit consists of the development board and the pinboard. More details about the Development Kit, please click to the following link: https://www.good-display.com/product/53/ GDEY029T94 www.good-display.com 30 37 2.9 inch Series GOOD DISPLAY

<!-- Page 31 -->

1. Power On • Supply VCI • Wait 10ms 2. Set Initial Configuration • Define SPI interface to communicate with MCU • HW Reset • SW Reset by Command 0x12 • Wait 10ms 3. Send Initialization Code • Set gate driver output by Command 0x01 • Set display RAM size by Command 0x11, 0x44, 0x45 • Set panel border by Command 0x3C 4. Load Waveform LUT • Sense temperature by int/ext TS by Command 0x18 • Load waveform LUT from OTP by Command 0x22, 0x20 or by MCU • Wait BUSY Low 5. Write Image and Drive Display Panel • Write image data in RAM by Command 0x4E, 0x4F, 0x24, 0x26 • Set softstart setting by Command 0x0C • Drive display panel by Command 0x22, 0x20 • Wait BUSY Low 6. Power Off • Deep sleep by Command 0x10 • Power OFF 14.Typical Operating Sequence 14.1 Normal Operation Flow GDEY029T94 www.good-display.com 31 37 2.9 inch Series GOOD DISPLAY

<!-- Page 32 -->

15.Inspection condition 15.1 Environment Temperature ： 25±3 ℃ Humidity ： 55±10%RH 15.2 Illuminance Brightness:1200 ～ 1500LUX;distance:20-30CM;Angle:Relate 30°surround. 15.4 Display area 15.3 Inspection method GDEY029T94 www.good-display.com 32 37 2.9 inch Series GOOD DISPLAY

<!-- Page 33 -->

15.5 Inspection standard 15.5.1 Electric inspection standard GDEY029T94 www.good-display.com 33 37 2.9 inch Series GOOD DISPLAY

<!-- Page 34 -->

15.5.2 Appearance inspection standard GDEY029T94 www.good-display.com 34 37 2.9 inch Series GOOD DISPLAY

<!-- Page 35 -->

GDEY029T94 www.good-display.com 35 37 2.9 inch Series GOOD DISPLAY

<!-- Page 36 -->

1 6 . Packing GDEY029T94 www.good-display.com 36 37 2.9 inch Series GOOD DISPLAY

<!-- Page 37 -->

17 . Precautions (1) Do not apply pressure to the EPD panel in order to prevent damaging it. (2) Do not connect or disconnect the interface connector while the EPD panel is in operation. (3) Do not touch IC bonding area. It may scratch TFT lead or damage IC function. (4) Please be mindful of moisture to avoid its penetration into the EPD panel, which may cause damage during operation. (5) If the EPD Panel / Module is not refreshed every 24 hours, a phenomena known as “Ghosting” or “Image Sticking” may occur. It is recommended to refreshed the ESL /EPD Tag every 24 hours in use case. It is recommended that customer ships or stores the ESL / EPD Tag with a completely white image to avoid this issue (6) High temperature, high humidity, sunlight or fluorescent light may degrade the EPD panel’s performance. Please do not expose the unprotected EPD panel to high temperature, high humidity, sunlight, or fluorescent for long periods of time. (7) For more precautions, please click on the link: http s ://www.good-display.com/news/80.html GDEY029T94 www.good-display.com 37 37 2.9 inch Series GOOD DISPLAY

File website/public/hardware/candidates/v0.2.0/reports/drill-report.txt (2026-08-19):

Drill report for the-card.kicad_pcb
Created on 2026-08-20T00:35:38

Copper Layer Stackup:
    =============================================================
    L1 :  F.Cu                      front
    L2 :  In1.Cu                    in1
    L3 :  In2.Cu                    in2
    L4 :  B.Cu                      back

Drill file 'the-card-PTH.drl' contains
    plated through holes:
    =============================================================
    T1  0.250mm  0.0098"  (18 holes))
    T2  0.300mm  0.0118"  (177 holes))
    T3  0.350mm  0.0138"  (38 holes))
    T4  0.800mm  0.0315"  (4 holes)  (with 4 slots)

    Total plated holes count 237

Drill file 'the-card-NPTH.drl' contains
    unplated through holes:
    =============================================================
    T1  0.600mm  0.0236"  (2 holes))

    Total unplated holes count 2

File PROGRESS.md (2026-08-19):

# Progress — the-card

> Living status log for the ESP32-S3 e-paper smart badge. Last updated 2026-08-19.

## Status

🟢 **Design v0.2.0 single-page schematic and routed four-layer PCB source generated
   (KiCad 10, 78 parts).** The revision adds the mandatory NFC GPO pull-up, moves
   its interrupt off a strap pin, and replaces the provisional antenna with a
   tunable nine-turn coil in an all-layer RF quiet area. Automated ERC/DRC and
   connectivity checks are release gates; antenna resonance and range remain
   mandatory measurements on the first assembled board. The earlier v0.1.0
   draft remains available through Git history, not as a fabrication download.

---

## Completed

### 1. Product definition
ESP32-S3 based **DIY / learning smart badge**: e-paper wallpaper, Bluetooth, NFC,
watch-style buttons, on-board sensors, lanyard form factor. Open-source, MIT.

### 2. Documentation baseline (English)
- `README.md` — project brief + key takeaways
- `docs/architecture.md` — block diagram, subsystem design, **GPIO pin map**
- `docs/bom.md` — full BOM (LCSC #s / prices) + landed-cost analysis
- `docs/power-budget.md` — state-based power model + battery-life scenarios

Headline numbers: component BOM ~$21.5 (@100), landed ~$28/unit. The corrected
datasheet-based daily-use model is about 5.4 months theoretical on a 1000 mAh
cell, with 4–5 months used only as a planning range until v0.2.0 is measured.

### 3. Repository
Local git repo, MIT license, `main` branch.

### 4. Toolchain (uv-managed, self-contained)
`skidl` (Python netlist) + `easyeda2kicad` (LCSC → KiCad libs). Web search via
Exa (API key in `~/.pi/web-search.json`). No KiCad GUI needed to generate the
netlist — only for later PCB layout.

### 5. BOM validation (caught by running easyeda2kicad early)
6 wrong/stale LCSC numbers found and fixed:

| Part | Was | Now |
|---|---|---|
| LSM6DSO | C967483 | C2655100 |
| USBLC6-2SC6 | C7936 | C7519 |
| DW01A | C142001 | C18164398 |
| FS8205A | C32253 | C16052 |
| WS2812B-Mini | C5275773 | C527089 |
| E-ink FPC connector | C262682 / C6081230 | FH12-24S-0.5SH(55), distributor |

Also caught: **ESP32-S3-WROOM-1 does not break out GPIO33/34**, and the selected
N16R8 variant also reserves GPIO35–37 for Octal PSRAM. `EPD_PWR_EN` therefore
uses GPIO16.

### 6. Schematic in code
`hardware/circuit.py` captures the full electrical design:
ESP32-S3 MCU · USB-C + ESD · TP4056 charger · DW01A + FS8205A protection ·
ME6211 LDO · MAX17048 fuel gauge · ST25DV04KC NFC · LSM6DSO IMU · SHT40 ·
WS2812 LED · 2× SI2301 power gates · 4× buttons · battery connector · e-ink FPC
connector and complete host-side SSD1680 boost network.

Power muxing: switchable AUX branch rail (Q1, status LED only) and a gated e-ink
VCI/booster input (Q2). The I²C sensors remain on +3V3 with the bus pullups to
avoid back-powering an unpowered device.

**Expected generated design: 78 components · 292 component pins · 43 canonical
named nets.** EN, IO0, battery,
3.3 V, and ground test points are included for first-board bring-up. Output:
`the-card.net` plus the generated single-page `the-card.kicad_sch`.

Reproducible pipeline: `parts.yaml → fetch_libs.sh → libraries/ → circuit.py → the-card.net`.

### 7. Datasheet verification (VERIFY items resolved)
Using Exa web search + the Good Display datasheet PDF:

- **DW01A + FS8205A** ✓ — pin mapping confirmed (EasyEDA `DOUT/VM/COUT` = HMSEMI
  `DO/CS/CO` = discharge / sense / charge). Found **3 missing required parts** and
  added them: R9 100 Ω (VCC←B+), R10 1 kΩ (VM←P-), C7 100 nF (VCC-VSS). Gate
  assignment DOUT→G1 / COUT→G2 and S1=B- / S2=P- is verified.
- **ST25DV04KC** ✓ — SO-8 pinout matches the symbol. Its GPO is open-drain, so
  Design v0.2.0 adds mandatory 10 kΩ pull-up R17 and connects `NFC_IRQ` to RTC-capable,
  non-strapping GPIO21 instead of GPIO3. The 28.5 pF internal tuning capacitance
  is modeled with distinct `NFC_AC0`/`NFC_AC1` nets, etched-coil model L2, and a
  DNP 0–22 pF C0G/NP0 tuning footprint C29. The SO-8 device has no LPD pin and is
  specified at 76 µA typical / 100 µA maximum static standby at 3.3 V (up to
  85 °C), not the previously assumed 1 µA.
- **GDEY029T94** ✓ — the assumed 8-signal pinout was **wrong**; the real 24-pin
  FFC brings out raw SSD1680 pins. Rewired: SPI on pins 9–14, VCI/VDDIO/VSS on
  15–17, BS1=GND (4-wire SPI), and intentionally unused pins marked NC. The
  panel-specific reference design confirms that the 47 µH boost stage, 30 V
  MOSFET/diodes, pump capacitors, and HV rail bypass capacitors are host-side;
  all are now included.

---

## Components & part numbers (authoritative: `hardware/parts.yaml`)

### Actives / ICs / connectors (LCSC)

| Ref | Part | LCSC | Role |
|---|---|---|---|
| U1 | ESP32-S3-WROOM-1-N16R8 | C2913202 | MCU (WiFi+BLE, 16 MB Flash, 8 MB Octal PSRAM) |
| U2 | ST25DV04KC-IE8S3 | C5221752 | NFC dynamic tag with GPO wake |
| U3 | LSM6DSOTR | C2655100 | 6-axis IMU |
| U4 | SHT40-BD1B-R2 | C7461849 | Temp / Humidity |
| U5 | MAX17048G+T10 | C2682616 | Li-ion fuel gauge (ModelGauge) |
| U6 | TP4056 | C382139 | Li-ion charger, configured for ~500 mA |
| U7 | DW01A | C18164398 | Battery protection IC |
| U8 | FS8205A | C16052 | Dual N-MOSFET (protection) |
| U9 | ME6211C33M5G | C82942 | LDO 3.3 V / 500 mA |
| U10 | USBLC6-2SC6 | C7519 | USB ESD protection |
| Q1, Q2 | SI2301 | C10487 | P-MOSFET ×2 (AUX rail + e-ink VCI gates) |
| Q3 | SI1308EDL-T1-GE3 | C469327 | 30 V N-MOSFET for e-paper boost stage |
| D1 | WS2812B-Mini | C527089 | RGB status LED |
| D2–D4 | LMBR0530T1G | C18863 | 30 V / 500 mA e-paper Schottky diodes |
| J1 | TYPE-C-31-M-12 | C165948 | USB-C receptacle |
| J3 | JST S2B-PH-SM4-TB(LF)(SN) | C295747 | 1S battery connector, right-angle SMT |
| SW1–4 | TS-1187A | C318884 | Tactile button ×4 |
| J2 | FH12-24S-0.5SH(55) | distributor | E-ink panel FPC (24 sig + 2 mount) |

### Display (not LCSC — distributor)
- **GDEY029T94** — 2.9" e-paper 296×128, SSD1680 (Good Display / buy-lcd / Waveshare)

### Assembly passives (exact LCSC/JLCPCB picks)

| Part | LCSC | Used for |
|---|---|---|
| 100 nF 16 V X7R 0402 (CL05B104KO5NNNC) | C1525 | C1/C4/C7/C10–C12/C14–C19 |
| 10 µF 10 V X5R 0603 (CL10A106KP8NNNC) | C19702 | C2/C5/C6/C13 |
| 1 µF 50 V X5R 0603 (CL10A105KB8NNNC) | C15849 | C3/C8/C9 |
| 4.7 µF 25 V X5R 0805 (CL21A475KAQNNNE) | C1779 | C20/C21 |
| 1 µF 50 V X7R 0805 (CL21B105KBFNNNE) | C28323 | C22–C28 |
| 0402 resistors, value-specific MPNs | C11702/C25076/C25744/C25774/C25879/C25900/C25905/C26083 | R1–R15, R17 |
| 2.2 Ω 0.75 W pulse-rated 1206 (CRCW12062R20FKEAHP) | C1854860 | R16 |

C29 is a DNP 0–22 pF C0G/NP0 tuning footprint and L2 represents copper etched into
the PCB; neither is an initially populated assembly item.

Battery (3.7 V 1000 mAh, 603048) and lanyard hardware are sourced from
distributors (no LCSC number).

---

## ✅ Datasheet verification (done) — full part cross-check

Beyond the three flagged sections (§7), every active part's pinout/connections
were cross-checked against the archived datasheets using pypdf text extraction:
USBLC6-2 (D±/VBUS/GND), TP4056 (TEMP/CE/PROG), MAX17048 (CTG/QSTRT/CELL),
LSM6DSO (CS=high→I²C, addr), ME6211 (CE active-high), SI2301 (1=G/2=S/3=D),
SHT40 (1=SDA/2=SCL/3=VDD/4=VSS). **No wiring errors found.**

The selected ME6211C33 is specified at 60 µA typical supply current while
enabled. Its 0.1 µA standby figure applies only with CE low; this design ties CE
to `+BAT`, so the power model uses 60 µA.

TP4056 RPROG is 2.2 kΩ, limiting charge current to approximately 500 mA. This is
a more conservative first-board setting for the planned 1000 mAh cell and gives
the linear charger more thermal margin.

Remaining items are first-prototype validation risks, not CAD blockers:

- **DW01A+FS8205A** — topology and routing are complete; verify U8 orientation
  and negative-path continuity before connecting a cell.
- **ST25DV04KC antenna** — design v0.2.0 uses a nine-turn, 0.20 mm F.Cu spiral in an
  all-copper-layer quiet area. The ST square-equivalent heuristic gives about
  4.52 µH, while an NXP rectangular-coil cross-check brackets about
  3.19–3.98 µH. That lower bracket implies roughly 6.1–14.7 pF nominal added
  capacitance before antenna stray capacitance and assembly loading. Keep C29
  DNP initially; measure assembled resonance/Q, then select the smallest
  suitable C0G/NP0 value and test read/write range with multiple phones in the
  final display/battery enclosure. Treat a required value above about 15–18 pF,
  poor Q, or inadequate range as an antenna-respin signal.
- **FH12 FPC orientation** — verify the physical panel FPC reaches the
  bottom-contact connector without twisting before ordering.
- **JST-PH battery polarity** — confirm the selected cell's cable orientation.

---

## Next steps (roadmap)

- [x] Confirm the 3 VERIFY items against datasheets
- [x] Generate and verify a single-page `.kicad_sch` from `circuit.py`
- [x] Generate, route, and verify the four-layer PCB layout
- [ ] Order and bring up the first prototype
- [ ] ESP-IDF firmware scaffold: display / button / NFC / BLE modules + deep-sleep wake flow
- [ ] Mechanical: case + lanyard CAD

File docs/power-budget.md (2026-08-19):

# Power Budget & Battery-Life Estimate

> Target battery: **3.7 V 1000 mAh Li-Po** (~900 mAh usable at 90% derating).
> Units: current mA / charge mAh. Battery life = usable capacity ÷ daily consumption.
> These are planning estimates from bundled component datasheets, not measured
> v0.2.0 results; firmware duty cycle, cell quality, temperature, and regulator
> dropout will change the real runtime.

---

## 1. Per-state Current Model (ESP32-S3-WROOM-1-N16R8)

Sources: ESP32-S3 datasheet + Espressif official power-measurement guide +
community measurements. The corrected always-on figures come from the bundled
[ST25DV04KC datasheet](../hardware/datasheets/ST25DV04KC_ST.pdf) (DS13519 Rev 3,
Table 249) and [ME6211 datasheet](../hardware/datasheets/ME6211_Microne.pdf)
(ME6211C33 electrical-characteristics table).

| State | Module current | Notes |
|---|---|---|
| **Deep Sleep (RTC + ULP off)** | ~10 µA | module-level measured ~7–11 µA |
| Deep Sleep (ULP running) | ~180 µA | when ULP monitors a sensor |
| Light Sleep (auto) | ~0.13–0.24 mA | while keeping WiFi link |
| Modem Sleep (DTIM1) | ~20 mA | WiFi stays connected |
| Active (CPU 240 MHz, radios off) | ~40 mA | rendering an e-paper frame |
| Active + WiFi connect burst | ~150–250 mA (peak) | OTA / wallpaper download |
| BLE peripheral advertising (1 s) | ~3 mA (avg) | |
| BLE connected (1 s interval) | ~0.2–0.8 mA (avg) | |

## 2. Peripheral Current

| Peripheral | Standby / active current | Notes |
|---|---|---|
| E-paper SSD1680 | static **0 µA** (bistable) / ~3 mA during refresh (host boost stage) | during refresh the ESP is also Active, total ~30 mA |
| ST25DV04KC NFC | **0.076 mA typ, 0.100 mA max** (static standby at 3.3 V, up to 85 °C) | the selected SO-8 package has no LPD pin; RF operation can be field-powered |
| LSM6DSO IMU | LP 0.012 mA / shutdown 3 µA | |
| SHT40 T/RH | 0.0004 mA standby / 1.2 mA × 2 ms | negligible at 1/min sampling |
| MAX17048 fuel gauge | **0.003 mA (always on)** | can't be cut; always resident |
| ME6211C33 LDO | **0.060 mA typ supply current** | CE is tied high, so the 0.1 µA CE-low standby value does not apply |
| TP4056 (not charging) | ~0.005 mA (BAT side) | |
| WS2812 (**~0.6 mA even when off**) | **must be MOSFET-gated** | ⚠️ the biggest leakage killer |
| AUX branch rail after MOSFET cut | 0 µA | status LED fully cut; sensors remain on +3V3 |

> **Critical:** WS2812 still draws ~0.6 mA when "off" due to internal latching. Ungated, a 1000 mAh cell **lasts only ~60 days on leakage alone**. This project gates the branch rail via `PWR_AUX` (GPIO47) → P-MOSFET.

## 3. Deep-sleep Baseline (the core of runtime)

Always-on devices summed (MCU in deep sleep, branch rail cut):

```
ESP32-S3 deep sleep   10 µA
MAX17048 fuel gauge    3 µA
ST25DV04KC standby    76 µA
LSM6DSO LP mode       12 µA (or 3 µA shutdown)
SHT40 standby          0.4 µA
ME6211C33 enabled      60 µA
TP4056 BAT current     ~5 µA
divider network       ~2.8 µA (1 MΩ + 300 kΩ at ~3.7 V)
─────────────────────────
baseline total      ~169 µA  →  4.06 mAh/day
```

> With the IMU in shutdown (button-wake instead of motion-wake), the baseline is
> still about **160 µA (3.85 mAh/day)**. The always-enabled ME6211 and the SO-8
> ST25DV now dominate the estimate. The ST25DV datasheet's 1.3 µA low-power-down
> figure at 3.3 V is not available on the selected package because it has no LPD
> pin.

---

## 4. Battery-life Scenarios

### Scenario A — daily badge use (baseline)
> Glance at screen 10×/day, change wallpaper 2×, BLE sync to phone 2×, one nightly OTA check.

| Event | Times/day | Duration | Current | mAh/day |
|---|---|---|---|---|
| Deep-sleep baseline | — | 24 h | 169 µA | 4.06 |
| Button wake + UI render | 10 | 4 s | 40 mA | 0.44 |
| E-paper full refresh | 3 | 3 s | 30 mA | 0.075 |
| BLE sync (wallpaper push) | 2 | 15 s | 8 mA (avg) | 0.067 |
| WiFi OTA check | 1 | 20 s | 150 mA (avg) | 0.833 |
| **Daily total** | | | | **~5.5 mAh/day** |

**Life** = 900 / 5.5 ≈ **164 days (5.4 months theoretical)**. Use roughly
**4–5 months** as a first planning range; only measurements on an assembled v0.2.0
board with production firmware can establish a real runtime.

### Scenario B — light use (display-focused, rare OTA)
> Only change wallpaper, daily OTA off, BLE sync ~1×/week.

| Item | mAh/day |
|---|---|
| Deep-sleep baseline | 4.06 |
| Wake + render ×5 | 0.22 |
| Full refresh ×2 | 0.05 |
| BLE sync (weekly avg) | 0.01 |
| **Total** | **~4.3 mAh/day** |

**Life** ≈ **207 days (6.8 months theoretical)**; roughly **5–6 months** is a
reasonable planning range before prototype measurements.

### Scenario C — heavy development (radios always on)
> Persistent WiFi + serial logging + frequent refresh.

| Item | mAh/day |
|---|---|
| Modem/Light-sleep holding WiFi | ~480 (20 mA × 24 h) |
| Frequent CPU activity | ~50 |
| **Total** | **~530 mAh/day** |

**Life** ≈ **1.7 days** — normal in development; production firmware must turn off radios and deep-sleep.

### Scenario D — pure standby (factory state)
> Deep sleep only, wake once daily via RTC to refresh the clock.

With the IMU shut down, **life** ≈ 900 / 3.85 ≈ **234 days (7.7 months
theoretical)**. This is an electrical-load estimate, not a shelf-life guarantee.

---

## 5. Runtime-improvement Checklist (ranked)

| # | Measure | Saving | Difficulty |
|---|---|---|---|
| 1 | **Keep the WS2812 MOSFET-gated** | saves ~14 mAh/day of LED leakage | ⭐ must-do |
| 2 | Wake by RTC timer + buttons, not motion | saves IMU 0.3 mAh/day | ⭐ |
| 3 | Use 1 MΩ high-value VBATT divider, or sample only when awake | saves ~0.1 mAh/day | ⭐ |
| 4 | Consider an LPD-capable ST25DV package in a later hardware revision | about 1.8 mAh/day versus SO-8 static standby | ⭐⭐⭐ redesign |
| 5 | Stretch BLE connection interval to 1–4 s (tolerable for wallpaper push) | big BLE average drop | ⭐⭐ |
| 6 | Lower OTA-check frequency (daily → weekly) | saves ~0.8 mAh/day | ⭐ |
| 7 | Use partial refresh instead of full (0.3 s vs 1.5 s) | 5× lower refresh energy | ⭐⭐ |
| 8 | Underclock CPU to 80/160 MHz (enough for rendering) | ~30% lower active current | ⭐⭐ |
| 9 | ULP co-processor polls buttons/sensors | saves MCU wake overhead | ⭐⭐⭐ advanced |

---

## 6. Battery Sizing

| Capacity | Size (ref.) | Scenario A life | Trade-off |
|---|---|---|---|
| 500 mAh | 502030 (~5 mm) | ~2 months | ultra-thin, short runtime |
| **1000 mAh** ✅ | 603048 (~6 mm) | ~4–5 months | **recommended, balanced** |
| 1500 mAh | 803040 (~8 mm) | ~6–7 months | thicker, OK for a lanyard |
| 2000 mAh | 904050 (~9 mm) | ~8–10 months | bulky/heavy |

> Badge thickness should stay ≤8 mm → **1000–1500 mAh is the practical size
> range**. Runtime figures above are estimates and do not include a measured
> cell self-discharge curve.

---

## 7. Charge Time

- TP4056 set to approximately 500 mA charge current (`PROG` pin = 2.2 kΩ)
- 1000 mAh cell: CC phase ~2 h plus CV taper ≈ **full charge ~3 h**
- USB-C 5 V/1 A input is enough — no fast-charge needed

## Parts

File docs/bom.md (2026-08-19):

# Bill of Materials & Cost Analysis

> Prices reflect **2026-08** LCSC / JLCPCB / Good Display market data. Unit prices are reference values — confirm live at order time.
> **Reference quantity: @100 units** (small-batch / DIY group buy); @1 (prototype) and @1k (production trend) also listed.
> The cost table is planning data, not the assembly-house upload BOM. Exact
> purchasable codes are assigned in `hardware/parts.yaml`; recheck live stock,
> lifecycle status, and assembly availability when the order is placed.

📌 Price columns show **line totals** (unit price × "Qty"), not unit prices.
An em dash means the distributor quote has not yet been captured.

---

## 1. Core BOM

| # | Category | Part | MPN | LCSC | Qty | @1 (USD) | @100 (USD) | @1k (USD) |
|---|---|---|---|---|---|---|---|---|
| 1 | MCU | WiFi+BLE module | ESP32-S3-WROOM-1-N16R8 | C2913202 | 1 | 5.48 | **3.94** | 3.72 |
| 2 | Display | 2.9" e-paper 296×128 SSD1680 | GDEY029T94 (Good Display) | distributor¹ | 1 | 7.60 | **7.00** | 5.50 |
| 3 | Display aux | FPC connector 24P 0.5 mm ZIF | FH12-24S-0.5SH(55) | distributor | 1 | — | — | — |
| 4 | NFC | Dynamic tag IC with GPO wake | ST25DV04KC-IE8S3 | C5221752 | 1 | 0.91 | **0.55** | 0.44 |
| 5 | IMU | 6-axis accel + gyro | LSM6DSOTR | C2655100 | 1 | 3.50 | **2.50** | 2.20 |
| 6 | Temp/Humidity | Digital T/RH | SHT40-BD1B-R2 | C7461849 | 1 | 1.93 | **1.32** | 1.21 |
| 7 | Fuel gauge | Li-ion ModelGauge | MAX17048G+T10 | C2682616 | 1 | 2.50 | **1.50** | 1.35 |
| 8 | Charger | Li-ion charger, configured for ~500 mA | TP4056 (TPOWER) | C382139 | 1 | 0.20 | **0.12** | 0.10 |
| 9 | Protection | Battery protection IC | DW01A | C18164398 | 1 | 0.10 | 0.06 | 0.05 |
| 10 | Protection | Dual N-MOSFET | FS8205A | C16052 | 1 | 0.12 | 0.07 | 0.06 |
| 11 | Regulator | LDO 3.3 V 500 mA | ME6211C33M5G | C82942 | 1 | 0.15 | 0.10 | 0.08 |
| 12 | Switch | P-MOSFET (branch-rail gate) | SI2301 | C10487 | 2 | 0.20 | **0.12** | 0.10 |
| 13 | LED | RGB status | WS2812B-Mini | C527089 | 1 | 0.20 | 0.12 | 0.10 |
| 14 | Connector | USB-C receptacle 6P | TYPE-C-31-M-12 | C165948 | 1 | 0.25 | 0.15 | 0.12 |
| 15 | ESD | USB bidirectional TVS | USBLC6-2SC6 | C7519 | 1 | 0.18 | 0.12 | 0.10 |
| 16 | Button | Tactile switch 6×6×5 SMD | TS-1187A | C318884 | 4 | 0.24 | **0.16** | 0.12 |
| 17 | Display aux | 47 µH boost network, 30 V MOSFET/diodes | XRNR5020-47uH/M / SI1308EDL-T1-GE3 / LMBR0530T1G | C5339697 / C469327 / C18863 | 1 set | 0.80 | 0.45 | 0.30 |
| 18 | Connector | 1S battery connector, 2-pin right-angle SMT | JST S2B-PH-SM4-TB(LF)(SN) | C295747 | 1 | 0.22 | 0.17 | 0.13 |
| 19 | Passives | Exact R/C set, including 50 V e-paper rail capacitors and pulse-rated R16 | 0402/0603/0805/1206 | see `hardware/parts.yaml` | 1 set | 0.60 | 0.35 | 0.25 |
| 20 | Hardware | Lanyard / clip hardware | — | distributor | 1 kit | 1.00 | 0.50 | 0.35 |
| 21 | Battery | Li-Po 3.7 V 1000 mAh | 603048 | distributor | 1 | 4.00 | **2.50** | 2.00 |
| 22 | PCB | 4-layer, 0.8 mm | JLCPCB | — | 1 | 5.00 | **1.50** | 0.80 |

¹ E-paper panels are bought from the OEM (Good Display / 大连佳显), buy-lcd.com, or Waveshare. LCSC sometimes stocks them but the model range is incomplete.

### Component subtotal (excl. #20 hardware and #22 PCB)

| Tier | Subtotal |
|---|---|
| **@1 (prototype)** | ≈ $29.4 |
| **@100 (small batch)** | ≈ **$21.4** |
| **@1k (production)** | ≈ $18.0 |

---

## 2. Landed Cost (incl. PCBA + case)

| Item | @1 | @100 | @1k |
|---|---|---|---|
| Components (incl. panel/battery) | 29.4 | 21.4 | 18.0 |
| PCB (4-layer, 0.8 mm) | 5.0 | 1.5 | 0.8 |
| SMT assembly + stencil | —² | 1.5 | 0.9 |
| Case (3D print / DIY) | 3.0 | 2.0 | 0.8 (injection) |
| Lanyard hardware | 1.0 | 0.5 | 0.35 |
| Assembly labor / test | 2.0 | 1.0 | 0.4 |
| **Per-unit total** | **~$40** | **~$28** | **~$21** |

² A single prototype is usually hand-soldered or run as a 1-off PCBA order (adds ~$15–30 NRE, high when amortized to one board).

> Recommendation: **first run 5–10 prototypes** (PCBA ~$40–50 each), validate, then do a small batch of 100 (~$28/unit).

---

## 3. Cost-Structure Breakdown

```
@100 unit component breakdown (base $21.4)
E-paper   █████████████████        33%   ← biggest line item
MCU       █████████                18%
IMU       ██████                   12%
Battery   ██████                   12%
Fuel gauge███                       7%
T/RH      ███                       6%
Rest      ██████                    12%  ← NFC / power / connectors / passives
```

### Cost-reduction Levers (ranked by savings)

| Measure | Saving | Trade-off |
|---|---|---|
| Swap panel to 2.13" GDEY0213B74 (250×122) | -$3 | 30% less display area |
| Drop MCU to N8R2 (8 MB + 2 MB PSRAM) | No consistent current saving | Less OTA/image headroom |
| Drop MAX17048 fuel gauge, use divider only | -$1.5 | Inaccurate battery % (non-linear Li-ion curve) |
| Drop IMU (only T/RH + motion?) | -$2.5 | Loses flip-wake / step count |
| NFC → passive NTAG216 sticker | -$0.3 | Loses MCU dynamic rewrite / GPO wake |
| Swap to color 2.66" panel | **+$3** | 11 s refresh, worse UX |

**Verdict:** the current selection is already the **best value point** for a DIY/learning platform. To save more, touch the panel size first.

---

## 4. Sourcing & Ordering

### 4.1 Channel split
- **Main ICs and passives** → exact LCSC/JLCPCB codes are assigned in `hardware/parts.yaml`; recheck assembly stock at order time
- **E-paper panel** → Good Display / buy-lcd.com / Waveshare (note: **bare FPC panel** vs **module with driver board** — this project uses a bare panel on the PCB)
- **Battery** → a Li-Po specialist (mind protection/ Certification; air freight restricted)
- **Case** → 3D print (FDM/SLA) DIY, or injection molding at volume

### 4.2 BOM-kit strategy
- Load the generated assembly BOM into the cart and check current stock and SMT feasibility before payment
- **Basic-part** components incur no setup fee — preferring Basic parts saves ~$1/board
- Extended parts (e.g. MAX17048, LSM6DSO) add a small changeover fee, negligible at small batch

### 4.3 Risk / long lead-time parts
- **E-paper panel:** in peak season (Q4) lead time can stretch to 2–4 weeks; over-order the first batch by ~20%
- **ESP32-S3-WROOM-1-N16R8:** broadly stocked; confirm C2913202 inventory and price at order time
- **ST25DV04KC:** 2k+ in stock; the SO-8 package (C5221752) hand-solders better than UFDFPN — prefer SO-8
- **Battery:** air freight restricted (domestic ground for China); overseas buyers need a local Li-Po vendor

---

## 5. Optional Expansion (not in core BOM)

| Add-on | Model | Purpose | ~@100 |
|---|---|---|---|
| Digital mic | INMP441 / MSM261S4030H0 | Voice / recording | $1.2 |
| Ambient light | BH1750FVI | Auto contrast | $0.4 |
| Barometric pressure | BMP390 / LPS22HB | Altimeter / floors | $1.5 |
| External Flash | W25Q128 | Bigger wallpaper library | $0.6 |
| Solar | amorphous-Si low-light cell | Extend runtime via EH | $1.0 |

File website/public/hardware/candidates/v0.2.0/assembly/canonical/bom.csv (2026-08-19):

designators | quantity | value | footprint | lcsc_part_number | sourcing_status | source_hint | related_to | functions | notes
C1,C4,C7,C10,C11,C12,C14,C15,C16,C17,C18,C19 | 12 | 100nF | Capacitor_SMD:C_0402_1005Metric | C1525 | assigned | JLCPCB Basic | C1: U1 3V3; C4: U1 IO1 / battery ADC; C7: U7 VDD / BAT_NEG; C10: U5 CELL/VDD; C11: U2 VCC; C12: U3 VDD/VDDIO; C14: U4 VDD; C15: D1 VDD / AUX_3V3; C16: SW1 / U1 IO4; C17: SW2 / U1 IO5; C18: SW3 / U1 IO6; C19: SW4 / U1 IO7 | C1: MCU high-frequency supply decoupling; C4: Battery measurement low-pass filter; C7: Battery-protection supply decoupling; C10: Fuel-gauge supply decoupling; C11: NFC supply decoupling; C12: IMU high-frequency supply decoupling; C14: Humidity-sensor supply decoupling; C15: Addressable-LED supply decoupling; C16: UP-button hardware debounce; C17: DOWN-button hardware debounce; C18: SELECT-button hardware debounce; C19: MENU-button hardware debounce
C2,C5,C6,C13 | 4 | 10uF | Capacitor_SMD:C_0603_1608Metric | C19702 | assigned | JLCPCB Basic | C2: U1 3V3 / +3V3; C5: J1 / U10 / U6 VBUS; C6: U6 BAT / +BAT; C13: U3 VDD/VDDIO / +3V3 | C2: MCU local bulk capacitance; C5: USB input bulk capacitance; C6: Charger output and battery-rail bulk capacitance; C13: IMU local bulk capacitance
C3,C8,C9 | 3 | 1uF | Capacitor_SMD:C_0603_1608Metric | C15849 | assigned | JLCPCB Basic | C3: U1 EN; C8: U9 VIN; C9: U9 VOUT | C3: MCU reset and startup timing; C8: LDO input bypass and stability capacitance; C9: LDO output stability capacitance
C20,C21 | 2 | 4.7uF 25V | Capacitor_SMD:C_0805_2012Metric | C1779 | assigned | JLCPCB Basic | C20: J2 VCI / e-paper boost; C21: J2 / Q3 / EPD_PUMP | C20: E-paper switched-input bulk capacitance; C21: E-paper boost charge-pump capacitor
C22,C23,C24,C25,C26,C27,C28 | 7 | 1uF 50V | Capacitor_SMD:C_0805_2012Metric | C28323 | assigned | JLCPCB Basic | C22: J2 VDD; C23: J2 VSH2; C24: J2 VSH1; C25: J2 VGH; C26: J2 VSL; C27: J2 VGL; C28: J2 VCOM | C22: E-paper internal core-regulator bypass; C23: E-paper positive source-rail reservoir; C24: E-paper positive source-rail reservoir; C25: E-paper positive gate-rail reservoir; C26: E-paper negative source-rail reservoir; C27: E-paper negative gate-rail reservoir; C28: E-paper common-electrode rail reservoir
D1 | 1 | WS2812B-MINI | the-card:LED-SMD_4P-L3.5-W3.5-TL_WS2812B | C527089 | assigned | JLCPCB Extended
D2,D3,D4 | 3 | LMBR0530T1G | Diode_SMD:D_SOD-123 | C18863 | assigned | JLCPCB Extended
J1 | 1 | TYPE-C-31-M-12 | the-card:USB-C_SMD-TYPE-C-31-M-12_1 | C165948 | assigned | JLCPCB Extended
J2 | 1 | FH12-24S-0.5SH(55) | the-card:Hirose_FH12-24S-0.5SH_1x24-2MP_P0.50mm_Horizontal |  | distributor | distributor |  |  | bottom-contact ZIF, 0.5 mm pitch, for 0.30 mm FPC
J3 | 1 | S2B-PH-SM4-TB(LF)(SN) | Connector_JST:JST_PH_S2B-PH-SM4-TB_1x02-1MP_P2.00mm_Horizontal | C295747 | assigned | JLCPCB Extended |  |  | Right-angle SMT JST-PH. Battery cable polarity is not standardized; inspect the actual pack.
L1 | 1 | XRNR5020-47uH/M 47uH | the-card:IND-SMD_L5.0-W5.0_XRNR5020 | C5339697 | assigned | JLCPCB Extended
Q1,Q2 | 2 | SI2301CDS-T1-GE3 | the-card:SOT-23-3_L3.0-W1.7-P0.95-LS2.9-BR | C10487 | assigned | JLCPCB Basic
Q3 | 1 | SI1308EDL-T1-GE3 | Package_TO_SOT_SMD:SOT-323_SC-70 | C469327 | assigned | JLCPCB Extended
R1,R2,R8,R11,R12,R17 | 6 | 10k | Resistor_SMD:R_0402_1005Metric | C25744 | assigned | JLCPCB Basic | R1: U1 EN; R2: U1 IO0; R8: U6 CHRG / U1 IO15; R11: Q1 / U1 IO47; R12: Q2 / U1 IO16; R17: U2 GPO / U1 IO21 | R1: MCU enable pull-up to +3V3; R2: MCU boot-strap pull-up to +3V3; R8: Open-drain charge-status pull-up; R11: AUX rail P-MOSFET gate pull-up (default off); R12: E-paper P-MOSFET gate pull-up (default off); R17: NFC open-drain GPO pull-up to +3V3
R3,R15 | 2 | 1M | Resistor_SMD:R_0402_1005Metric | C26083 | assigned | JLCPCB Basic | R3: U1 IO1 / +BAT; R15: J2 GDR / Q3 | R3: Battery ADC divider, upper leg; R15: E-paper boost MOSFET gate pull-down
R4 | 1 | 300k | Resistor_SMD:R_0402_1005Metric | C4137657 | assigned | JLCPCB Extended | R4: U1 IO1 / GND | R4: Battery ADC divider, lower leg | Active Yageo replacement for the out-of-stock LCSC retail part.
R5,R6 | 2 | 5.1k | Resistor_SMD:R_0402_1005Metric | C25905 | assigned | JLCPCB Basic | R5: J1 CC1; R6: J1 CC2 | R5: USB-C sink configuration pull-down; R6: USB-C sink configuration pull-down
R7 | 1 | 2.2k | Resistor_SMD:R_0402_1005Metric | C25879 | assigned | JLCPCB Basic | R7: U6 PROG | R7: TP4056 charge-current programming (~500mA)
R9 | 1 | 100 | Resistor_SMD:R_0402_1005Metric | C25076 | assigned | JLCPCB Basic | R9: U7 VDD / +BAT | R9: Battery-protection supply feed resistor
R10 | 1 | 1k | Resistor_SMD:R_0402_1005Metric | C11702 | assigned | JLCPCB Basic | R10: U7 VM / GND | R10: Battery-protection pack-negative sense resistor
R13,R14 | 2 | 4.7k | Resistor_SMD:R_0402_1005Metric | C25900 | assigned | JLCPCB Basic | R13: I2C_SCL / U1-U5; R14: I2C_SDA / U1-U5 | R13: Shared I2C clock pull-up; R14: Shared I2C data pull-up
R16 | 1 | 2.2 | Resistor_SMD:R_1206_3216Metric | C1854860 | assigned | JLCPCB Extended | R16: J2 RESE / Q3 | R16: E-paper boost current-sense resistor | 1206 size provides pulse and power margin in the e-paper boost stage.
SW1,SW2,SW3,SW4 | 4 | TS-1187A-B-A-B | the-card:SW-SMD_4P-L5.1-W5.1-P3.70-LS6.5-TL_H1.5 | C318884 | assigned | JLCPCB Basic
U1 | 1 | ESP32-S3-WROOM-1-N16R8 | the-card:WIRELM-SMD_ESP32-S3-WROOM-1 | C2913202 | assigned | JLCPCB Extended
U2 | 1 | ST25DV04KC-IE8S3 | the-card:SO-8_L4.9-W3.9-P1.27-LS6.0-BL | C5221752 | assigned | JLCPCB Extended
U3 | 1 | LSM6DSOTR | the-card:LGA-14_L3.0-W2.5-P0.50-TL | C2655100 | assigned | JLCPCB Extended
U4 | 1 | SHT40-BD1B-R2 | the-card:DFN-4_L1.5-W1.5-P0.80-TL-EP | C7461849 | assigned | JLCPCB Extended
U5 | 1 | MAX17048G+T10 | the-card:TDFN-8_L2.0-W2.0-P0.50-BL-EP1.2 | C2682616 | assigned | JLCPCB Extended
U6 | 1 | TP4056_C382139 | the-card:ESOP-8_L4.9-W3.9-P1.27-LS6.0-BL-EP | C382139 | assigned | JLCPCB Extended
U7 | 1 | DW01A_C18164398 | the-card:SOT-23-6_L2.9-W1.6-P0.95-LS2.8-BR | C18164398 | assigned | JLCPCB Extended
U8 | 1 | 8205A | the-card:TSSOP-8_L4.4-W3.0-P0.65-LS6.4-BL-2 | C5148694 | assigned | JLCPCB Extended |  |  | Pin-compatible with the FS8205A symbol and existing TSSOP-8 footprint.
U9 | 1 | ME6211C33M5G-N | the-card:SOT-23-5_L3.0-W1.7-P0.95-LS2.8-BL | C82942 | assigned | JLCPCB Extended
U10 | 1 | USBLC6-2SC6 | the-card:SOT-23-6_L2.9-W1.6-P0.95-LS2.8-BL | C7519 | assigned | JLCPCB Extended

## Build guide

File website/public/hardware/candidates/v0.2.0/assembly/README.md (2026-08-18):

# Assembly outputs

`canonical/` contains vendor-neutral BOM, placement, and drawing data.
`jlcpcb/` contains upload-ready BOM and position files derived from the canonical data. J2 is intentionally distributor-sourced and has no LCSC part number.

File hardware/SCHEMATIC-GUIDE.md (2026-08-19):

# Single-page schematic layout guide (KiCad eeschema)

The schematic is generated as a hand-placed A2 landscape page. `circuit.py`
remains the electrical source of truth; this guide documents the intended grouping
and signal flow for reviewing or adjusting the placement tables in
`gen_hierarchical_schematic.py`.

The Python source uses semantic passive names such as `R_prog` and `C_epd_vcom`
inside the placement tables. `circuit.py` maps those names to conventional KiCad
references (`R7`, `C28`, and so on) in the generated schematic.

## Setup

1. Install KiCad: `brew install --cask kicad`
2. Open `hardware/` as a KiCad project (or create a new project there). The
   `sym-lib-table` / `fp-lib-table` already register our two libraries:
   - **the-card** — all actives/connectors (ESP32 module, ST25DV, …)
   - **passives** — R/C templates + the e-ink FPC connector
3. Generate and verify the schematic from `hardware/`:

   ```bash
   uv run python gen_hierarchical_schematic.py
   uv run python verify_schematic.py
   ```

Five functional regions share one A2 sheet: Power/USB across the upper left,
NFC/sensors across the upper right, MCU in the center, UI along the lower left,
and e-paper along the lower right. Named labels replace long cross-page wires.

## Power rails (global labels, reused across regions)

`+3V3` (always-on system rail) · `+BAT` (cell+) · `VBUS` (USB 5 V) ·
`AUX_3V3` (switched LED rail via Q1) · `EPD_VCI` (switched e-ink rail via Q2) ·
`GND` · `BAT_NEG` (cell-, ⚠️ not GND).

## Passive relationship and function annotations

Every resistor and capacitor has two generated KiCad properties:

- **Related To** identifies the owning IC, connector, switch, signal, rail, or
  shared circuit block. A shared bus or rail is not forced under one arbitrary IC.
- **Function** states why the component exists, such as decoupling, bulk storage,
  pull-up, filtering, timing, debounce, or charge-pump energy storage.

The properties remain hidden on the drawing to avoid text collisions, but are
available in symbol properties and BOM export. Compact callouts on the schematic
summarize the same relationships by functional block:

Support passives are placed beside the IC or functional block they serve. KiCad
junction dots are shown only where wires are electrically connected; a crossing
or geometric touch without a dot must not be interpreted as a connection.
Compact local circuits such as MCU EN/BOOT and charger CHRG support are wired
directly. Repeated endpoint labels are reserved for distant functional regions
or intentionally symbolic connections where a long wire would reduce clarity.

| References | Related to | Function |
|---|---|---|
| C1, C2 | U1 / +3V3 | MCU high-frequency bypass and local bulk storage |
| R1, C3 | U1 EN | Enable pull-up and startup/reset timing |
| R2 | U1 IO0 | Boot-strap pull-up |
| R3, R4, C4 | U1 IO1 / +BAT | Battery ADC divider and low-pass filter |
| C5, R5, R6 | J1 / U10 / U6 | USB input bulk storage and CC pull-downs |
| R7, R8, C6 | U6 / U1 | Charge-current setting, status pull-up, and BAT bulk storage |
| R9, R10, C7 | U7 / U8 | Protection supply feed, pack-negative sense, and bypass |
| C8, C9 | U9 | LDO input bypass and output stability |
| C10 | U5 | Fuel-gauge supply bypass |
| R11, R12 | Q1 / Q2 / U1 | Switched-rail gate pull-ups; both rails default off |
| C11, R13, R14, R17 | U2 / shared I2C bus | NFC bypass, I2C clock/data pull-ups, and mandatory GPO pull-up |
| L2, C29 (DNP) | U2 AC0/AC1 | Etched PCB antenna model and optional C0G resonance trim |
| C12, C13, C14 | U3 / U4 | IMU bypass and bulk storage; humidity-sensor bypass |
| C15 | D1 / AUX_3V3 | Addressable-LED supply bypass |
| C16-C19 | SW1-SW4 / U1 | Hardware button debounce |
| C20, C21 | J2 / Q3 / e-paper boost | Switched-input bulk and boost pump storage |
| R15, R16 | J2 / Q3 | Boost gate bias and current sensing |
| C22-C28 | J2 panel rails | Core, source, gate, and VCOM rail reservoirs |

## Region 1 — Power & Charging

Parts: J1 (USB-C) · U10 (USBLC6-2) · U6 (TP4056) · U7 (DW01A) · U8 (HXY 8205A) ·
U9 (ME6211 LDO) · U5 (MAX17048) · Q1, Q2 (SI2301) · J3 (battery) ·
TP1–TP4 · power passives.

- J1: VBUS→`VBUS`, GND+EH→GND, **CC1/CC2 each 5.1 k to GND**, DN1/DN2 and DP1/DP2
  into U10. SBU1/SBU2 NC.
- U10 (USBLC6-2SC6, SOT-23-6): I/O1 (pin1,6)=D- path, I/O2 (pin3,4)=D+ path,
  pin2=GND, pin5=VBUS. → `USB_DM`/`USB_DP` to MCU.
- U6 (TP4056): VCC←VBUS, BAT→`+BAT`, PROG→2.2 k→GND (~500 mA), TEMP→GND (no NTC), CE→VBUS,
  ~CHRG→10 k pullup to +3V3 → net `~CHRG` (to MCU). Add 10 µF on VBUS and on +BAT.
- U7+U8 protection: VDD(pin5)←100 Ω←+BAT, VSS(pin6)→`BAT_NEG`, VM(pin2)←1 k←GND,
  DOUT(pin1)→8205A G1, COUT(pin3)→G2; 100 nF VDD-VSS. 8205A: S1→BAT_NEG,
  S2→GND, D12=floating internal node.
- U9 (ME6211): VIN←+BAT, VOUT→`+3V3`, CE←+BAT (always on), 1 µF in/out.
- U5 (MAX17048): CELL+VDD←+BAT, CTG+QSTRT→GND, SCL/SDA→I²C, ~ALRT NC, 100 nF on VDD.
- J3: pin 1→`+BAT`, pin 2→`BAT_NEG`. Confirm the actual battery cable polarity;
  JST-PH packs are not universally wired the same way.
- Q1 (AUX rail): S→+3V3, D→`AUX_3V3`, G←net `PWR_AUX` + 10 k pullup to +3V3.
- Q2 (e-ink rail): S→+3V3, D→`EPD_VCI`, G←net `EPD_PWR_EN` + 10 k pullup.
- TP1–TP4 expose `+BAT`, `BAT_NEG`, `+3V3`, and `GND` for bring-up.

## Region 2 — MCU (ESP32-S3-WROOM-1, U1)

- 3V3→`+3V3`; 3× GND→GND; 100 nF + 10 µF on 3V3.
- EN: 10 k pullup to +3V3 + 1 µF to GND; TP5 permits a temporary reset-to-GND jumper.
- IO0: 10 k pullup to +3V3; TP6 permits a temporary boot-to-GND jumper.
  **IO33/IO34 are not on the module, and N16R8 reserves IO35–37 for Octal
  PSRAM — don't use them.**
- USB: IO19=`USB_DM`, IO20=`USB_DP` (from the power region).
- E-ink SPI: IO9=MOSI, IO10=SCLK, IO11=BUSY, IO12=CS, IO13=DC, IO14=RST.
- I²C: IO8=SCL, IO18=SDA (+ 4.7 k pullups to +3V3 in the sensor region).
- IRQs/status: IO21=`NFC_IRQ`, IO2=`IMU_INT`, IO15=`~CHRG`.
- Buttons: IO4=UP, IO5=DOWN, IO6=SEL, IO7=MENU.
- Controls: IO47=`PWR_AUX`, IO16=`EPD_PWR_EN`, IO48=`LED_DIN`.
- Vbat divider: IO1 ← midpoint of 1 M / 300 k from +BAT to GND (+ 100 nF).
- Spare (IO3, IO38–42, IO45/46, RXD0/TXD0): left unconnected for future
  revisions. GPIO3 is strap-sensitive and must not replace GPIO21 for NFC wake;
  IO35–37 are reserved by the N16R8 module's Octal PSRAM.

## Region 3 — E-ink panel (J2, 24-pin FPC)

GDEY029T94 pinout and support circuit (verified against the Good Display reference
design). Wire from the J2 connector:

- 8 (BS1)→GND (4-wire SPI) · 15+16 (VDDIO+VCI)→`EPD_VCI` · 17 (VSS)→GND ·
  18 (VDD core)→1 µF/50 V→GND.
- 9=BUSY · 10=RES# · 11=D/C# · 12=CS# · 13=SCL · 14=SDA(MOSI)  ← from MCU SPI nets
- GDR/RESE drive Q3 (SI1308EDL-T1-GE3) through the 47 µH boost network; use a
  1 MΩ gate pulldown and a 0.75 W pulse-rated 2.2 Ω RESE current-sense resistor.
- D2–D4 are LMBR0530T1G Schottky diodes. The boost input and pump use
  4.7 µF/25 V; VSH2, VSH1, VGH, VSL, VGL, and VCOM each use 1 µF/50 V to GND.
- 1, 4, 6, 7, and 19 are intentionally NC; 25 and 26 (shell)→GND.

## Region 4 — NFC + IMU + Temp/Humidity (I²C bus)

- I²C pullups: 4.7 k on `I2C_SCL` and `I2C_SDA` to +3V3.
- U2 (ST25DV04KC): VCC→+3V3, VSS→GND, SCL/SDA→I²C, V_EH NC. GPO is
  open-drain, so R17 provides its mandatory 10 kΩ pull-up to +3V3 before
  `NFC_IRQ` reaches GPIO21.
- AC0 and AC1 remain distinct as `NFC_AC0` and `NFC_AC1`. L2 is the schematic
  model/net tie for the nine-turn F.Cu antenna etched into the PCB. C29 is a
  DNP 0–22 pF C0G/NP0 footprint across the two antenna nets; leave it
  unpopulated until assembled resonance is measured.
- The ST square-equivalent heuristic gives about 4.52 µH, while an NXP
  rectangular-coil cross-check brackets about 3.19–3.98 µH. The PCB reserves a
  quiet area through all four copper layers, but these estimates omit assembly
  loading and do not replace measuring resonance, Q, and phone read/write range
  in the final enclosure.
- U3 (LSM6DSO): VDD+VDDIO→`+3V3`, GND→GND, SCL/SDA→I²C, INT1→`IMU_INT`,
  CS→`+3V3` (=high→I²C mode), SDO/SA0→GND (addr 0x6A); 100 nF + 10 µF on +3V3.
- U4 (SHT40): VDD→`+3V3`, VSS→GND, exposed pad NC, SCL/SDA→I²C; 100 nF on VDD.

Keeping the sensors on the same always-on rail as the I²C pullups prevents the
bus from back-powering an unpowered sensor. `AUX_3V3` therefore powers only D1.

## Region 5 — UI: buttons + LED

- SW1–4 (TS-1187A): pin A→`BTN_UP/DOWN/SEL/MENU`, pin C→GND, 100 nF across each.
- D1 (WS2812B-Mini): VDD→`AUX_3V3`, DIN←`LED_DIN`, VSS→GND, 100 nF on VDD.

## After layout changes

- Regenerate from the script; do not maintain one-off generated-file edits.
- Run `verify_schematic.py`; expect 78 components and 292 pins with identical
  peer sets across 43 canonical named nets from `circuit.py`.
- Run **Inspect → Electrical Rules Checker** in eeschema. Expect 0 violations.
- Then **Tools → Update PCB from Schematic** (or import `the-card.net`) to start layout.

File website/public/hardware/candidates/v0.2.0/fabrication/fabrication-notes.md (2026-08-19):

# Fabrication and first-assembly notes

This file is the handoff checklist for the first prototype. The KiCad design is
the source of truth; manufacturer settings must not silently change its layer
order or finished thickness.

## PCB order

- Four copper layers, 0.80 mm finished thickness, FR-4.
- Layer use: F.Cu signals/GND pour; In1.Cu primary GND; In2.Cu primary +3V3 and
  longer signals; B.Cu signals/GND pour.
- The v0.2.0 NFC antenna is a nine-turn, 0.20 mm F.Cu spiral. Its marked quiet
  area must remain free of unrelated pads, tracks, vias, and filled zones on
  **all four copper layers**; do not let a board-house review refill that void.
- Use the board house's 0.8 mm four-layer stackup with approximately 0.10 mm
  prepreg between F.Cu and In1.Cu (JLCPCB's 3313-family option is the reference).
- Outer copper 1 oz and inner copper 0.5 oz.
- Specify 90 Ω differential impedance for `USB_DP`/`USB_DM`, referenced from
  F.Cu to the continuous In1.Cu ground plane. Confirm the final trace width and
  spacing in the selected board house's current calculator before ordering; do
  not substitute the thicker 7628 outer dielectric without recalculation.
- The board rules are 0.15 mm minimum track, 0.20 mm default clearance, and
  0.50/0.25 mm minimum via/drill. The FPC and USB net classes intentionally use
  local 0.10/0.15 mm clearances.
- ENIG is preferred for the 0.5 mm-pitch FPC connector and 0402 parts because it
  is flatter than HASL. Use green solder mask for the lowest-risk first build.

The board currently uses the ESP32-S3 full-speed USB interface. The
length-matched pair and uninterrupted In1.Cu reference remain required even
though it is not the 480 Mb/s high-speed USB mode.

## Before assembly

1. Print a 1:1 board plot and place the actual display FPC over J2. Confirm that
   panel pin 1 reaches the `J2 PIN 1` end without twisting the cable and that the
   exposed contacts face the connector's bottom contacts after folding.
2. Identify the actual battery connector with a multimeter. J3 pin 1 must be
   cell positive (`BAT+`); J3 pin 2 must be cell negative (`BAT-`/`BAT_NEG`).
3. Confirm the cell is a bare, unprotected 1S Li-ion/LiPo if the on-board
   DW01A/8205A protection is populated. A protected pack is electrically safe
   but duplicates cut-off circuitry and can complicate recovery behavior.
4. Inspect U8 orientation and verify continuity before connecting a cell:
   S1 side to `BAT_NEG`, S2 side to system GND, and the common drains internal.
5. Confirm C29 is **not populated** for the initial antenna measurement. L2 is
   etched PCB copper/net-tie metadata, not an assembly-line inductor.

## First power-up

1. Leave the battery disconnected. Power from a current-limited 5 V USB supply
   and confirm VBUS and +3V3 at TP3/TP4.
2. Connect a current-limited cell simulator or protected test cell with the
   USB supply removed. Confirm polarity at TP1/TP2 before connecting it.
3. Confirm charge current and TP4056 temperature before a long charge test.
4. Bring up the display only after +3V3 and the switched `EPD_VCI` rail are
   correct. Check the e-paper high-voltage rails with an appropriate probe.
5. Confirm `NFC_IRQ` idles high through R17 and that an RF event can pull the
   ST25DV open-drain GPO low without disturbing boot behavior.

## NFC physical acceptance

Passing ERC and DRC proves connectivity and spacing, not RF performance. On an
assembled v0.2.0 board, with the real display, battery, and enclosure present:

1. Keep C29 DNP and measure antenna resonance and Q. The ST square-equivalent
   heuristic gives about 4.52 µH, while an independent NXP rectangular-coil
   cross-check brackets about 3.19–3.98 µH. These calculations omit final
   assembly loading and are sanity bounds, not acceptance measurements.
2. If resonance is above 13.56 MHz, calculate and fit the smallest suitable
   0–22 pF C0G/NP0 value at C29, then measure again. Do not populate a guessed
   value from the model alone; needing more than about 15–18 pF is a PCB-respin
   review trigger rather than automatic approval to fit 22 pF.
3. Verify NFC reads and writes with multiple representative phones, at several
   orientations, and record reliable range. Repeat after final assembly.
4. Treat failed tuning, poor Q, or inadequate range as a PCB-spin issue even if
   the automated release gates remain green.

## Release gate

Regenerate the schematic and PCB, then require all of the following from the
same committed design: connectivity verifier passes, KiCad ERC has zero
violations, KiCad DRC has zero violations, zero unconnected items, and zero
schematic parity issues, and the Gerber/drill preview matches the
53.98 x 85.60 mm outline.

The project has one design identity: `DESIGN_VERSION` in `design_metadata.py`.
The release tool reads it directly; there is no independent revision or release
version argument to mistype. The full value appears in both KiCad title blocks,
the Gerber metadata, and `release.json`. The limited board silkscreen derives a
major/minor mark from it, such as `HW 0.2` for v0.2.0.

Before v1.0.0, advance the minor version for any electrical, copper, stackup,
outline, footprint, connector, or other physical change. A package-only fix
that does not change the board may advance the patch version; its silkscreen
therefore still identifies the same major/minor PCB family. Never overwrite an
already published version. v1.0.0 is reserved for the first physically
assembled and accepted design. The unbuilt v0.1.0 draft remains in Git history
only and must not be offered as a fabrication download.

Build the handoff into a new directory from `hardware/`:

```bash
uv run python scripts/release_fabrication.py \
  --output ../outputs/the-card-hardware-v0.2.0
```

The command refuses to overwrite an existing output directory or release from a
dirty worktree. By default it creates 2D review material from the tracked design
without depending on the ignored supplier 3D-model directory. Add
`--include-3d` only when every model referenced by the board is available and
has been reviewed; this adds `preview/3d/` renders but does not change the
fabrication files.

The generated handoff is organized by audience:

```text
the-card-hardware-v0.2.0/
├── fabrication/
│   ├── gerbers/                       # production Gerbers
│   ├── drill/                         # separate PTH/NPTH Excellon files
│   ├── fabrication-notes.md           # stackup and ordering cautions
│   └── the-card-hardware-v0.2.0-fabrication.zip
├── preview/
│   ├── schematic.pdf + schematic.svg + schematic.png
│   ├── schematic-thumbnail.png
│   ├── pcb.pdf + pcb-front.png + two inner PNGs + pcb-back.png
│   ├── schematic/ + pcb/ + layers/ + drill/
│   ├── 3d/                            # only with --include-3d
│   └── the-card-hardware-v0.2.0-preview.zip
├── assembly/
│   ├── canonical/                     # normalized CSV/JSON + assembly drawings
│   ├── jlcpcb/                        # upload-ready BOM and position CSVs
│   └── the-card-hardware-v0.2.0-assembly.zip
├── reports/                           # ERC, DRC/parity, and drill reports
├── release.json                       # versioned manifest and provenance
└── SHA256SUMS                         # hashes every published file above
```

`fabrication/the-card-hardware-v0.2.0-fabrication.zip` contains only the
Gerbers and separate PTH/NPTH drill files intended for the board house. The
assembly data, reports, checksums, manifest, and review material remain outside
that ZIP. Do not upload the whole release directory, preview archive, or
assembly archive as the PCB fabrication archive. `release.json` deliberately
records the physical approval state as pending; passing automated gates does
not complete the physical checks below.

The release includes the detailed internal sourcing BOM plus the upload-ready
`assembly/jlcpcb/bom.csv` and `assembly/jlcpcb/positions.csv` pair. The
normalized, board-house-independent records and printable front/back assembly
drawings are kept under `assembly/canonical/`.
The JLC BOM follows the requested eight-column format and assigns exact
LCSC/JLCPCB codes in `JLCPCB Part #` to every board-placed electrical component
except J2, the intentionally distributor-sourced Hirose FPC connector. The JLC
position file uses millimetres, `Top`/`Bottom` layer names, and KiCad's exported
counter-clockwise rotations. Recheck stock, lifecycle status, package, and
assembly-side rotation against the generated position file before placing an
order; a closed BOM is not a substitute for the board house's live
manufacturability review.

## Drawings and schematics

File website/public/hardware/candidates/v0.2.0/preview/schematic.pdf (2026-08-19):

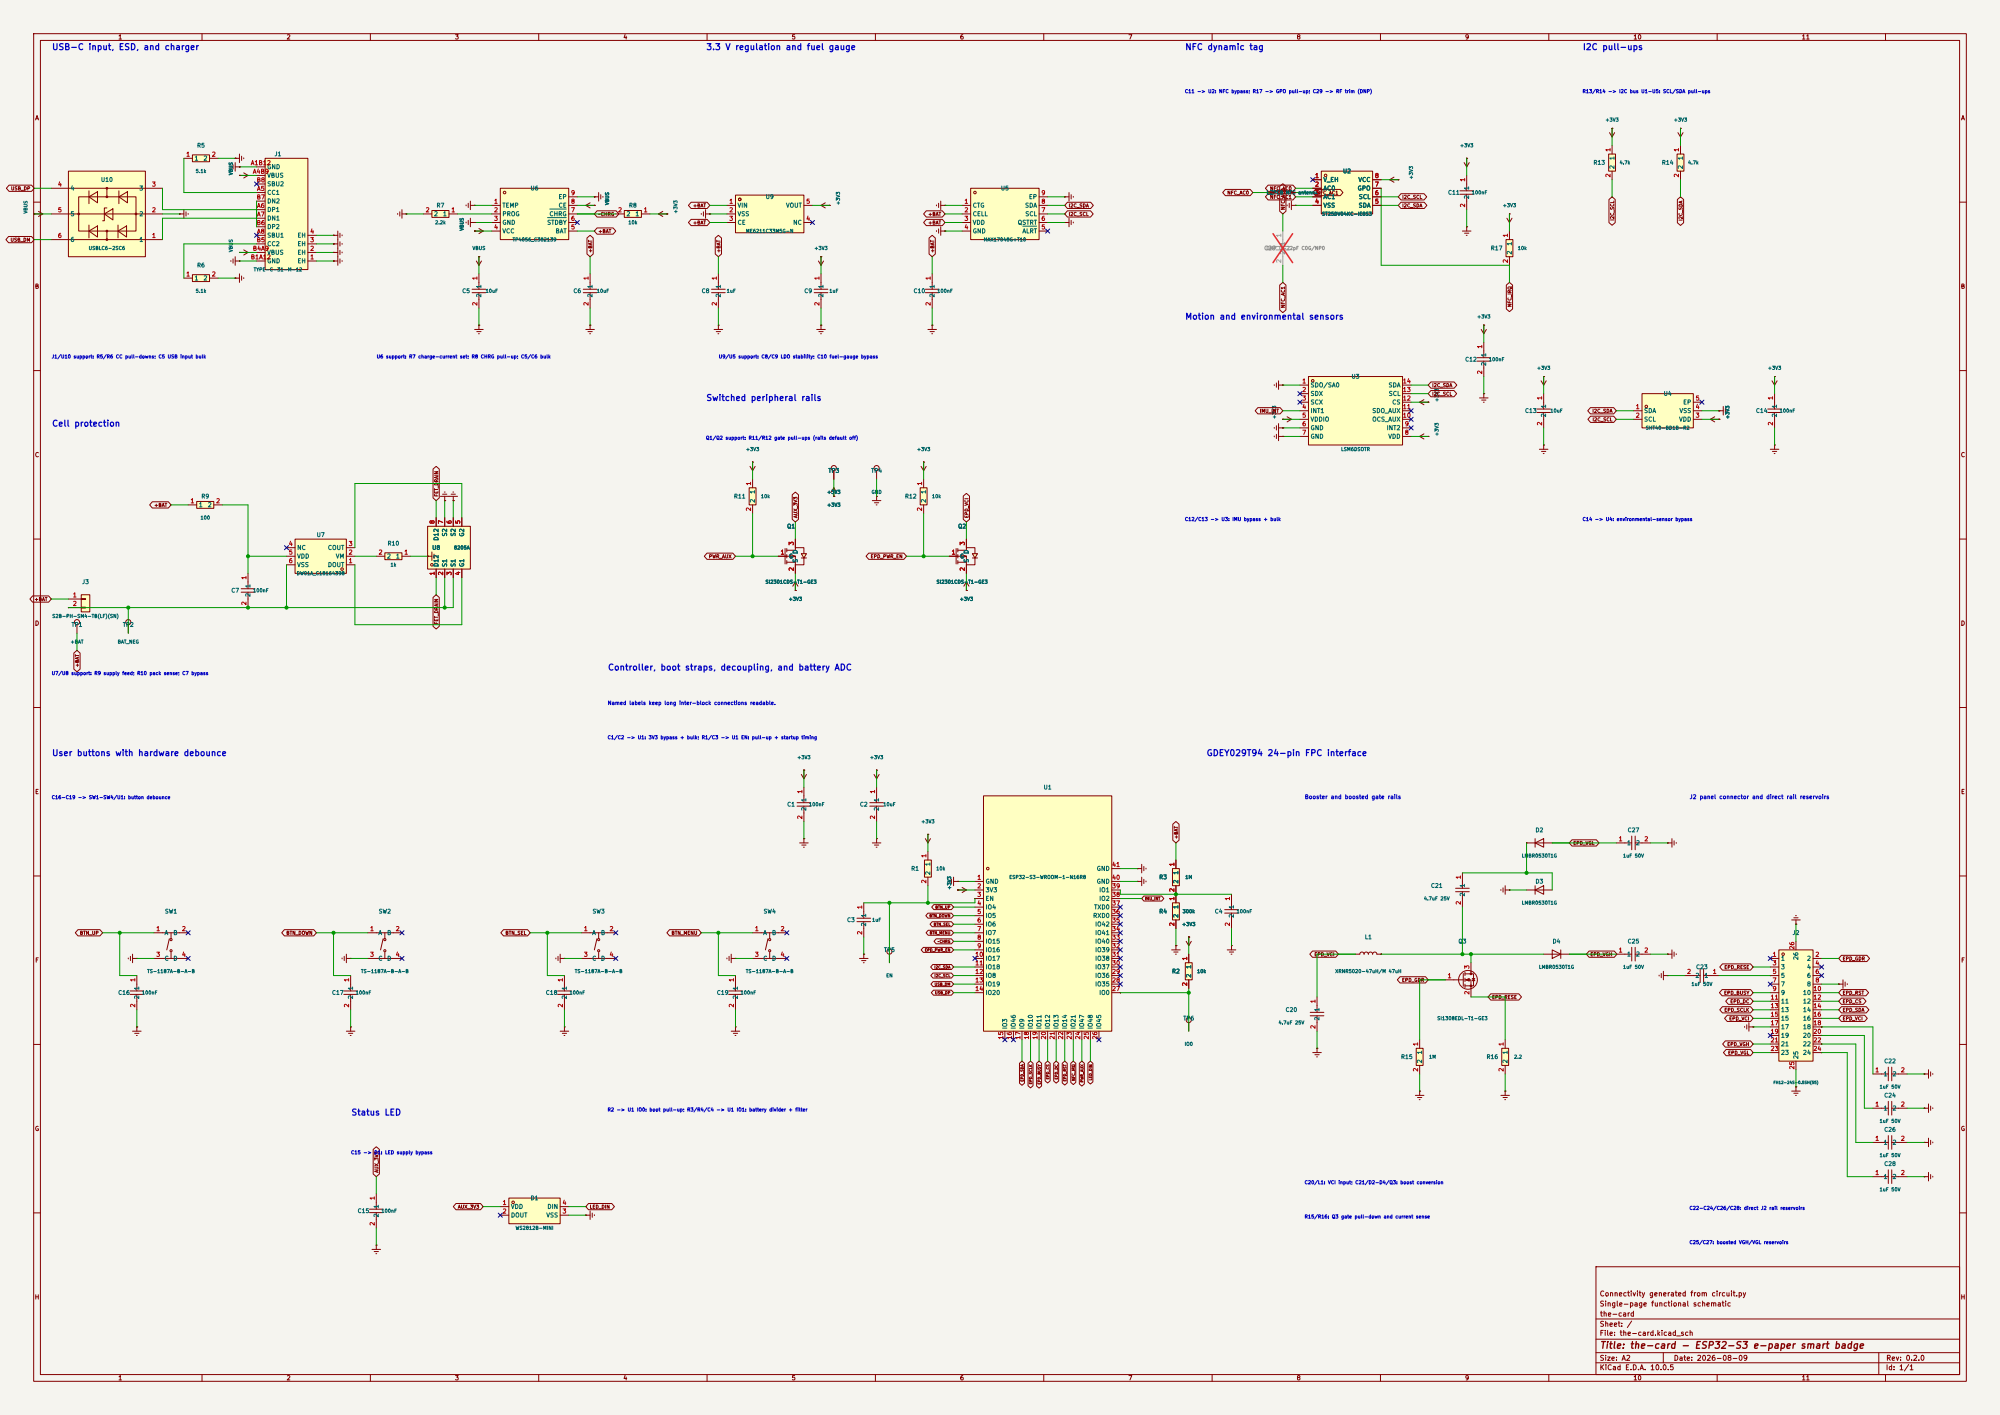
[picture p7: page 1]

USB-C input, ESD, and charger

3.3 V regulation and fuel gauge
SI1308EDL-T1-GE3 +3V3 1

C11 -> U2: NFC bypass; R17 -> GPO pull-up; C29 -> RF trim (DNP)

Motion and environmental sensors
IMU_INT EPD_RST

U9/U5 support: C8/C9 LDO stability; C10 fuel-gauge bypass Q1/Q2 support: R11/R12 gate pull-ups (rails default off)
+3V3 EPD_SDA

C12/C13 -> U3: IMU bypass + bulk C16-C19 -> SW1-SW4/U1: button debounce

C14 -> U4: environmental-sensor bypassJ2 panel connector and direct rail reservoirs GDEY029T94 24-pin FPC interface

Controller, boot straps, decoupling, and battery ADC

U7/U8 support: R9 supply feed; R10 pack sense; C7 bypass

Named labels keep long inter-block connections readable. C1/C2 -> U1: 3V3 bypass + bulk; R1/C3 -> U1 EN: pull-up + startup timing

User buttons with hardware debounce

C15 -> D1: LED supply bypass Status LED

C20/L1: VCI input; C21/D2-D4/Q3: boost conversion

C25/C27: boosted VGH/VGL reservoirs

Connectivity generated from circuit.py
Single-page functional schematic
the-card
Sheet: /
File: the-card.kicad_sch
Title: the-card - ESP32-S3 e-paper smart badge

Size: A2 | Rev: 0.2.0
KiCad E.D.A. 10.0.5 | Id: 1/1

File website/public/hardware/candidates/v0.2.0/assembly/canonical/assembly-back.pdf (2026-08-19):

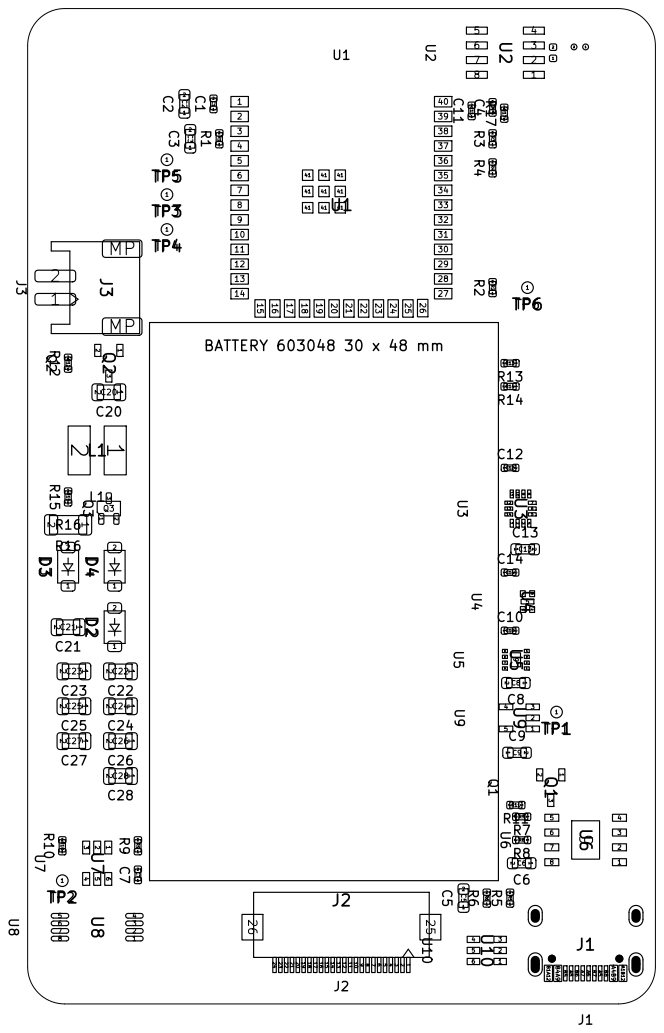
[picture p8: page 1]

Size: A4 | Rev: 0.2.0
KiCad E.D.A. 10.0.5 | Id: 1/1

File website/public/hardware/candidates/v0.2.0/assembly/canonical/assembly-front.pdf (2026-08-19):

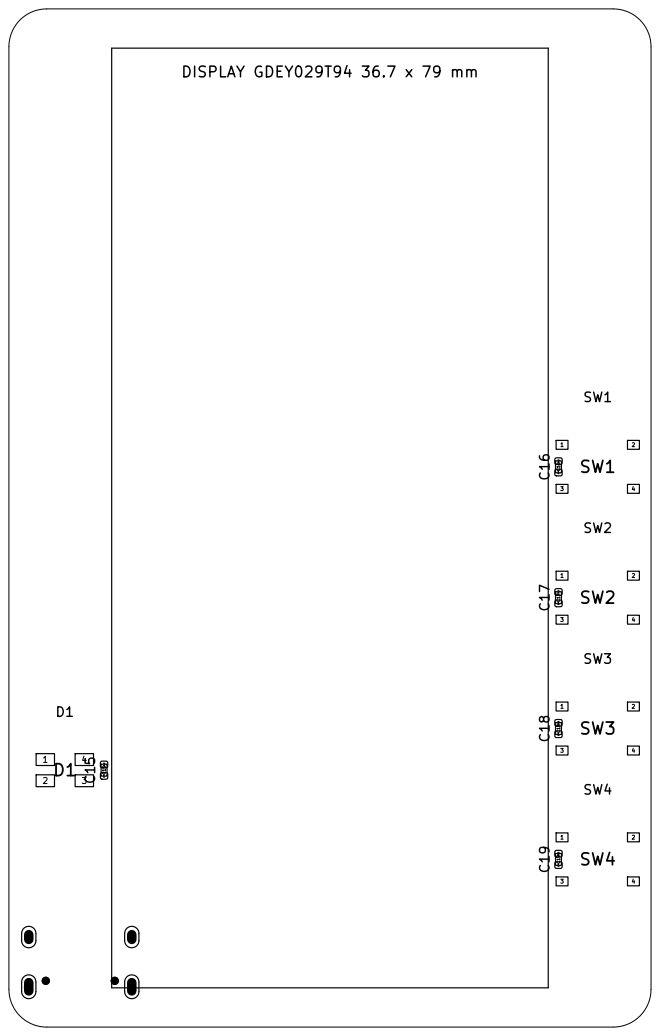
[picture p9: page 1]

Size: A4 | Rev: 0.2.0
KiCad E.D.A. 10.0.5 | Id: 1/1

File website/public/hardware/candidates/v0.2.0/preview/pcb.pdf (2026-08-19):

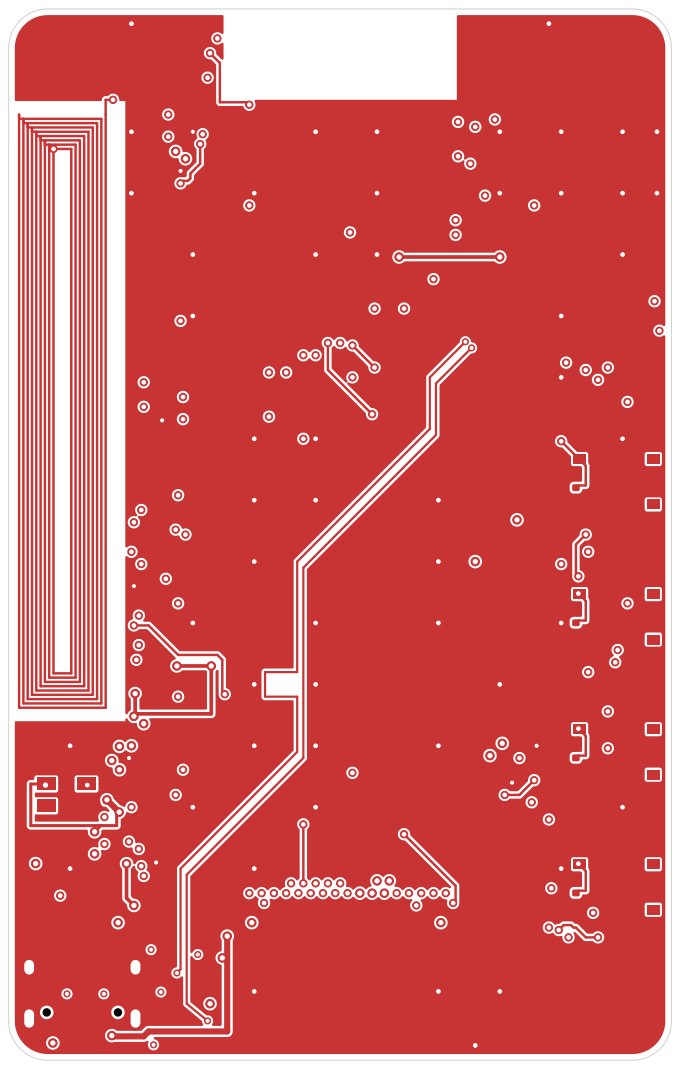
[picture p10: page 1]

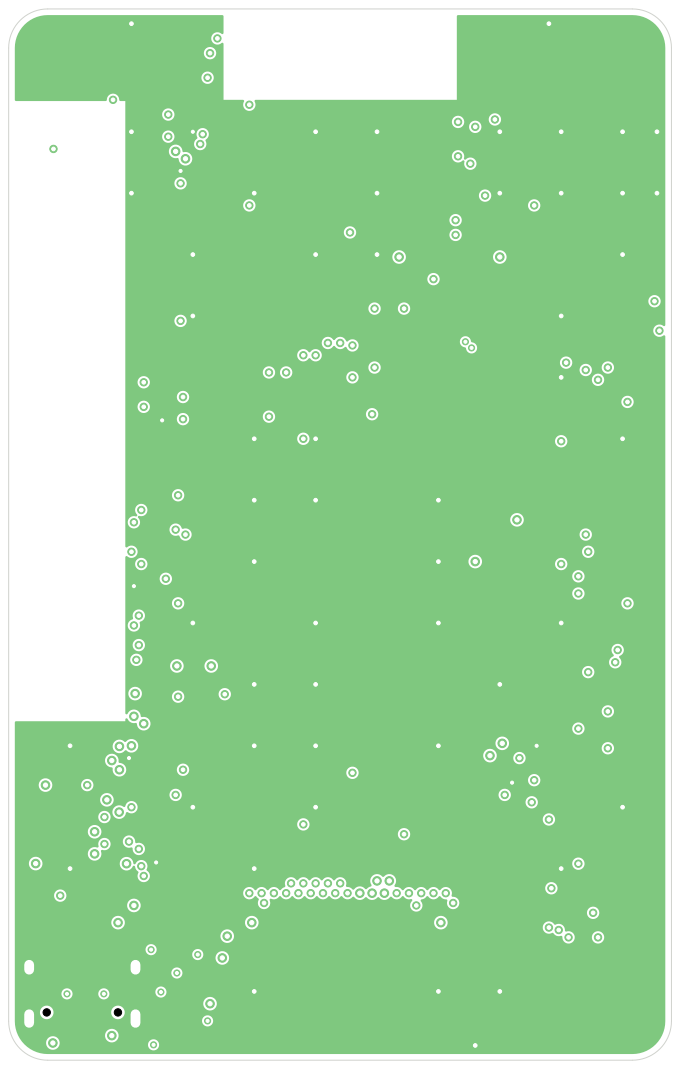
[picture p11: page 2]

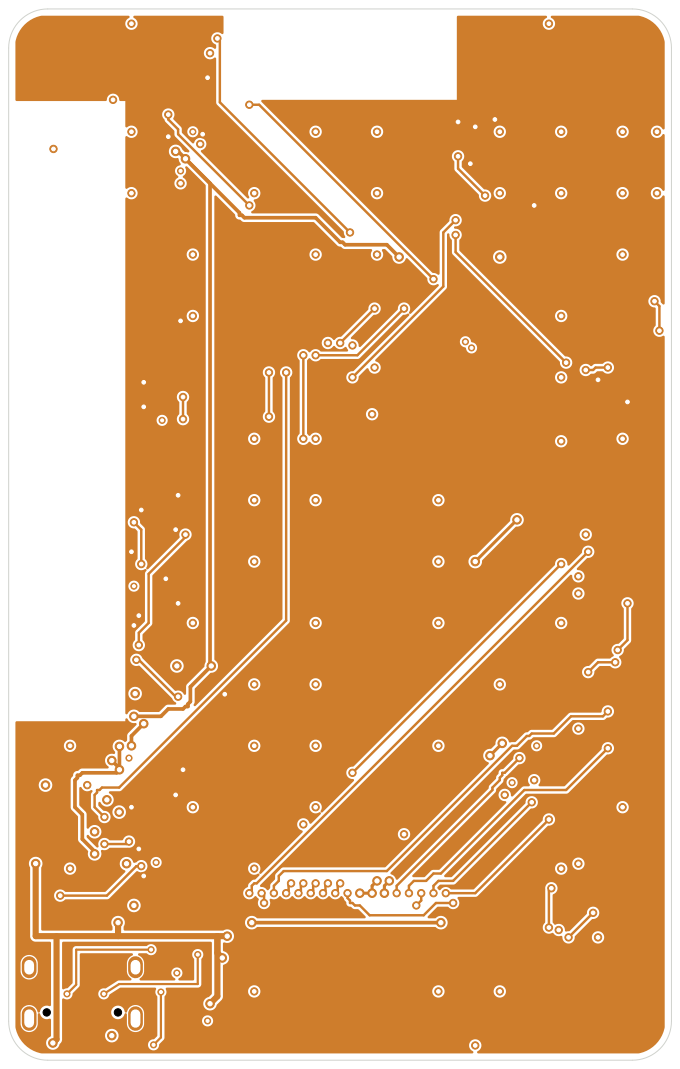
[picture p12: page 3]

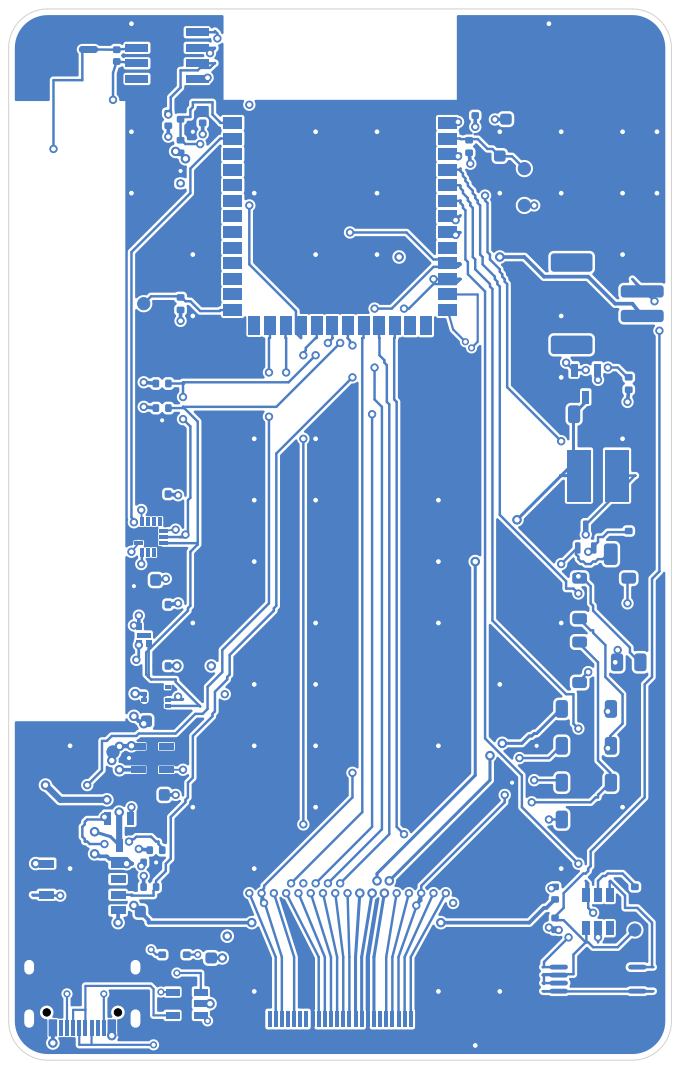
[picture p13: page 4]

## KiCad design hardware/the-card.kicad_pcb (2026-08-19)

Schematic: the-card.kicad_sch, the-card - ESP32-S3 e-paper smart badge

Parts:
C1, C4, C7, C10, C11, C12, C14, C15, C16, C17, C18, C19: 100nF; C_0402_1005Metric
C2, C5, C6, C13: 10uF; C_0603_1608Metric
C3, C8, C9: 1uF; C_0603_1608Metric
C20, C21: 4.7uF 25V; C_0805_2012Metric
C22, C23, C24, C25, C26, C27, C28: 1uF 50V; C_0805_2012Metric
C29: DNP 0-22pF C0G/NP0; C_0402_1005Metric; not fitted
D1: WS2812B-MINI; LED-SMD_4P-L3.5-W3.5-TL_WS2812B
D2, D3, D4: LMBR0530T1G; D_SOD-123
J1: TYPE-C-31-M-12; USB-C_SMD-TYPE-C-31-M-12_1
J2: FH12-24S-0.5SH(55); Hirose_FH12-24S-0.5SH_1x24-2MP_P0.50mm_Horizontal
J3: S2B-PH-SM4-TB(LF)(SN); JST_PH_S2B-PH-SM4-TB_1x02-1MP_P2.00mm_Horizontal
L1: XRNR5020-47uH/M 47uH; IND-SMD_L5.0-W5.0_XRNR5020
L2: PCB NFC antenna; NetTie-2_SMD_Pad0.5mm
Q1, Q2: SI2301CDS-T1-GE3; SOT-23-3_L3.0-W1.7-P0.95-LS2.9-BR
Q3: SI1308EDL-T1-GE3; SOT-323_SC-70
R1, R2, R8, R11, R12, R17: 10k; R_0402_1005Metric
R3, R15: 1M; R_0402_1005Metric
R4: 300k; R_0402_1005Metric
R5, R6: 5.1k; R_0402_1005Metric
R7: 2.2k; R_0402_1005Metric
R9: 100; R_0402_1005Metric
R10: 1k; R_0402_1005Metric
R13, R14: 4.7k; R_0402_1005Metric
R16: 2.2; R_1206_3216Metric
SW1, SW2, SW3, SW4: TS-1187A-B-A-B; SW-SMD_4P-L5.1-W5.1-P3.70-LS6.5-TL_H1.5
TP1: +BAT; TestPoint_Pad_D1.0mm
TP2: BAT_NEG; TestPoint_Pad_D1.0mm
TP3: +3V3; TestPoint_Pad_D1.0mm
TP4: GND; TestPoint_Pad_D1.0mm
TP5: EN; TestPoint_Pad_D1.0mm
TP6: IO0; TestPoint_Pad_D1.0mm
U1: ESP32-S3-WROOM-1-N16R8; WIRELM-SMD_ESP32-S3-WROOM-1
U2: ST25DV04KC-IE8S3; SO-8_L4.9-W3.9-P1.27-LS6.0-BL
U3: LSM6DSOTR; LGA-14_L3.0-W2.5-P0.50-TL
U4: SHT40-BD1B-R2; DFN-4_L1.5-W1.5-P0.80-TL-EP
U5: MAX17048G+T10; TDFN-8_L2.0-W2.0-P0.50-BL-EP1.2
U6: TP4056_C382139; ESOP-8_L4.9-W3.9-P1.27-LS6.0-BL-EP
U7: DW01A_C18164398; SOT-23-6_L2.9-W1.6-P0.95-LS2.8-BR
U8: 8205A; TSSOP-8_L4.4-W3.0-P0.65-LS6.4-BL-2; MPN 8205A; LCSC Part C5148694
U9: ME6211C33M5G-N; SOT-23-5_L3.0-W1.7-P0.95-LS2.8-BL
U10: USBLC6-2SC6; SOT-23-6_L2.9-W1.6-P0.95-LS2.8-BL

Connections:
+3V3: C1.1, C2.1, C9.1, C11.1, C12.1, C13.1, C14.1, Q1.2 (S), Q2.2 (S), R1.1, R2.1, R8.1, R11.1, R12.1, R13.1, R14.1, R17.1, TP3.1, U1.2 (3V3), U2.8 (VCC), U3.5 (VDDIO), U3.8 (VDD), U3.12 (CS), U4.3 (VDD), U9.5 (VOUT)
+BAT: C6.1, C8.1, C10.1, J3.1, R3.1, R9.1, TP1.1, U5.2 (CELL), U5.3 (VDD), U6.5 (BAT), U9.1 (VIN), U9.3 (CE)
AUX_3V3: C15.1, D1.1 (VDD), Q1.3 (D)
BAT_NEG: C7.2, J3.2, TP2.1, U7.6 (VSS), U8.2 (S1), U8.3 (S1)
BTN_DOWN: C17.1, SW2.1 (A), U1.5 (IO5)
BTN_MENU: C19.1, SW4.1 (A), U1.7 (IO7)
BTN_SEL: C18.1, SW3.1 (A), U1.6 (IO6)
BTN_UP: C16.1, SW1.1 (A), U1.4 (IO4)
EPD_BUSY: J2.9, U1.19 (IO11)
EPD_CS: J2.12, U1.20 (IO12)
EPD_DC: J2.11, U1.21 (IO13)
EPD_GDR: J2.2, Q3.1 (G), R15.1
EPD_PUMP: C21.1, D2.1 (K), D3.2 (A)
EPD_PWR_EN: Q2.1 (G), R12.2, U1.9 (IO16)
EPD_RESE: J2.3, Q3.2 (S), R16.1
EPD_RST: J2.10, U1.22 (IO14)
EPD_SCLK: J2.13, U1.18 (IO10)
EPD_SDA: J2.14, U1.17 (IO9)
EPD_SW: C21.2, D4.2 (A), L1.2, Q3.3 (D)
EPD_VCI: C20.1, J2.15, J2.16, L1.1, Q2.3 (D)
EPD_VCOM: C28.1, J2.24
EPD_VDD_CORE: C22.1, J2.18
EPD_VGH: C25.1, D4.1 (K), J2.21
EPD_VGL: C27.1, D2.2 (A), J2.23
EPD_VSH1: C24.1, J2.20
EPD_VSH2: C23.1, J2.5
EPD_VSL: C26.1, J2.22
FET_DRAIN: U8.1 (D12), U8.8 (D12)
GND: C1.2, C2.2, C3.2, C4.2, C5.2, C6.2, C8.2, C9.2, C10.2, C11.2, C12.2, C13.2, C14.2, C15.2, C16.2, C17.2, C18.2, C19.2, C20.2, C22.2, C23.2, C24.2, C25.2, C26.2, C27.2, C28.2, D1.3 (VSS), D3.1 (K), J1.1 (EH), J1.2 (EH), J1.3 (EH), J1.4 (EH), J1.A1B12 (GND), J1.B1A12 (GND), J2.8, J2.17, J2.25, J2.26, R4.2, R5.2, R6.2, R7.2, R10.1, R15.2, R16.2, SW1.3 (C), SW2.3 (C), SW3.3 (C), SW4.3 (C), TP4.1, U1.1 (GND), U1.40 (GND), U1.41 (GND), U2.4 (VSS), U3.1 (SDO/SA0), U3.6 (GND), U3.7 (GND), U4.4 (VSS), U5.1 (CTG), U5.4 (GND), U5.6 (QSTRT), U5.9 (EP), U6.1 (TEMP), U6.3 (GND), U6.9 (EP), U8.6 (S2), U8.7 (S2), U9.2 (VSS), U10.2
I2C_SCL: R13.2, U1.12 (IO8), U2.6 (SCL), U3.13 (SCL), U4.2 (SCL), U5.7 (SCL)
I2C_SDA: R14.2, U1.11 (IO18), U2.5 (SDA), U3.14 (SDA), U4.1 (SDA), U5.8 (SDA)
IMU_INT: U1.38 (IO2), U3.4 (INT1)
LED_DIN: D1.4 (DIN), U1.25 (IO48)
MCU_BOOT: R2.2, TP6.1, U1.27 (IO0)
MCU_EN: C3.1, R1.2, TP5.1, U1.3 (EN)
NFC_AC0: C29.1, L2.1, U2.2 (AC0)
NFC_AC1: C29.2, L2.2, U2.3 (AC1)
NFC_IRQ: R17.2, U1.23 (IO21), U2.7 (GPO)
unnamed: J1.A5 (CC1), R5.1
unnamed: J1.B5 (CC2), R6.1
unnamed: J1.A7 (DN1), J1.B7 (DN2), U10.1
unnamed: J1.A6 (DP1), J1.B6 (DP2), U10.3
unnamed: C4.1, R3.2, R4.1, U1.39 (IO1)
unnamed: R7.1, U6.2 (PROG)
unnamed: U7.3 (COUT), U8.5 (G2)
unnamed: U7.1 (DOUT), U8.4 (G1)
unnamed: C7.1, R9.2, U7.5 (VDD)
unnamed: R10.2, U7.2 (VM)
PWR_AUX: Q1.1 (G), R11.2, U1.24 (IO47)
USB_DM: U1.13 (IO19), U10.6
USB_DP: U1.14 (IO20), U10.4
VBUS: C5.1, J1.A4B9 (VBUS), J1.B4A9 (VBUS), U6.4 (VCC), U6.8 (CE), U10.5
~CHRG: R8.2, U1.8 (IO15), U6.7 (~CHRG)

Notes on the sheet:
USB-C input, ESD, and charger
3.3 V regulation and fuel gauge
Cell protection
Switched peripheral rails
J1/U10 support: R5/R6 CC pull-downs; C5 USB input bulk
U6 support: R7 charge-current set; R8 CHRG pull-up; C5/C6 bulk
U9/U5 support: C8/C9 LDO stability; C10 fuel-gauge bypass
U7/U8 support: R9 supply feed; R10 pack sense; C7 bypass
Q1/Q2 support: R11/R12 gate pull-ups (rails default off)
Controller, boot straps, decoupling, and battery ADC
Named labels keep long inter-block connections readable.
C1/C2 -> U1: 3V3 bypass + bulk; R1/C3 -> U1 EN: pull-up + startup timing
R2 -> U1 IO0: boot pull-up; R3/R4/C4 -> U1 IO1: battery divider + filter
NFC dynamic tag
Motion and environmental sensors
I2C pull-ups
C11 -> U2: NFC bypass; R17 -> GPO pull-up; C29 -> RF trim (DNP)
R13/R14 -> I2C bus U1-U5: SCL/SDA pull-ups
C12/C13 -> U3: IMU bypass + bulk
C14 -> U4: environmental-sensor bypass
GDEY029T94 24-pin FPC interface
Booster and boosted gate rails
J2 panel connector and direct rail reservoirs
C20/L1: VCI input; C21/D2-D4/Q3: boost conversion
R15/R16: Q3 gate pull-down and current sense
C22-C24/C26/C28: direct J2 rail reservoirs
C25/C27: boosted VGH/VGL reservoirs
User buttons with hardware debounce
Status LED
C16-C19 -> SW1-SW4/U1: button debounce
C15 -> D1: LED supply bypass

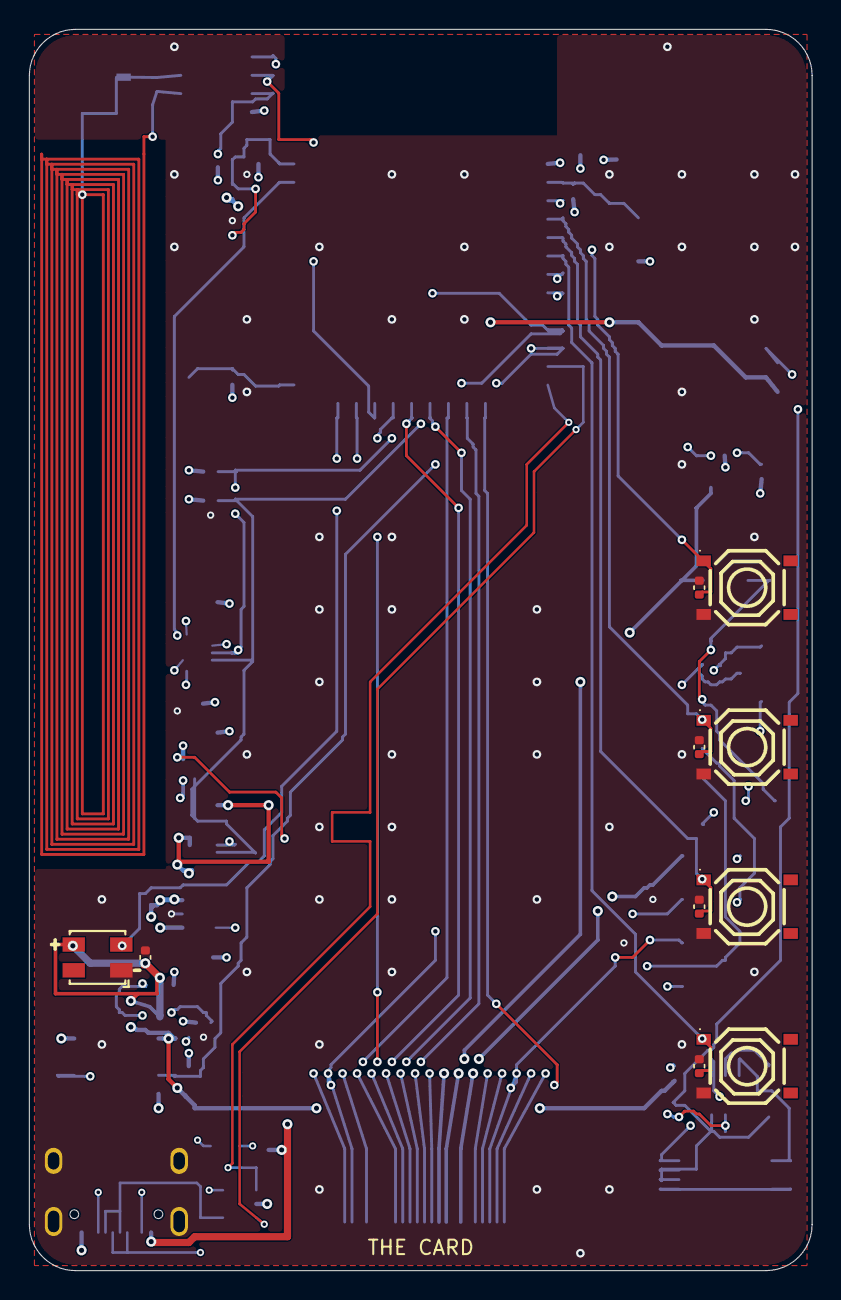
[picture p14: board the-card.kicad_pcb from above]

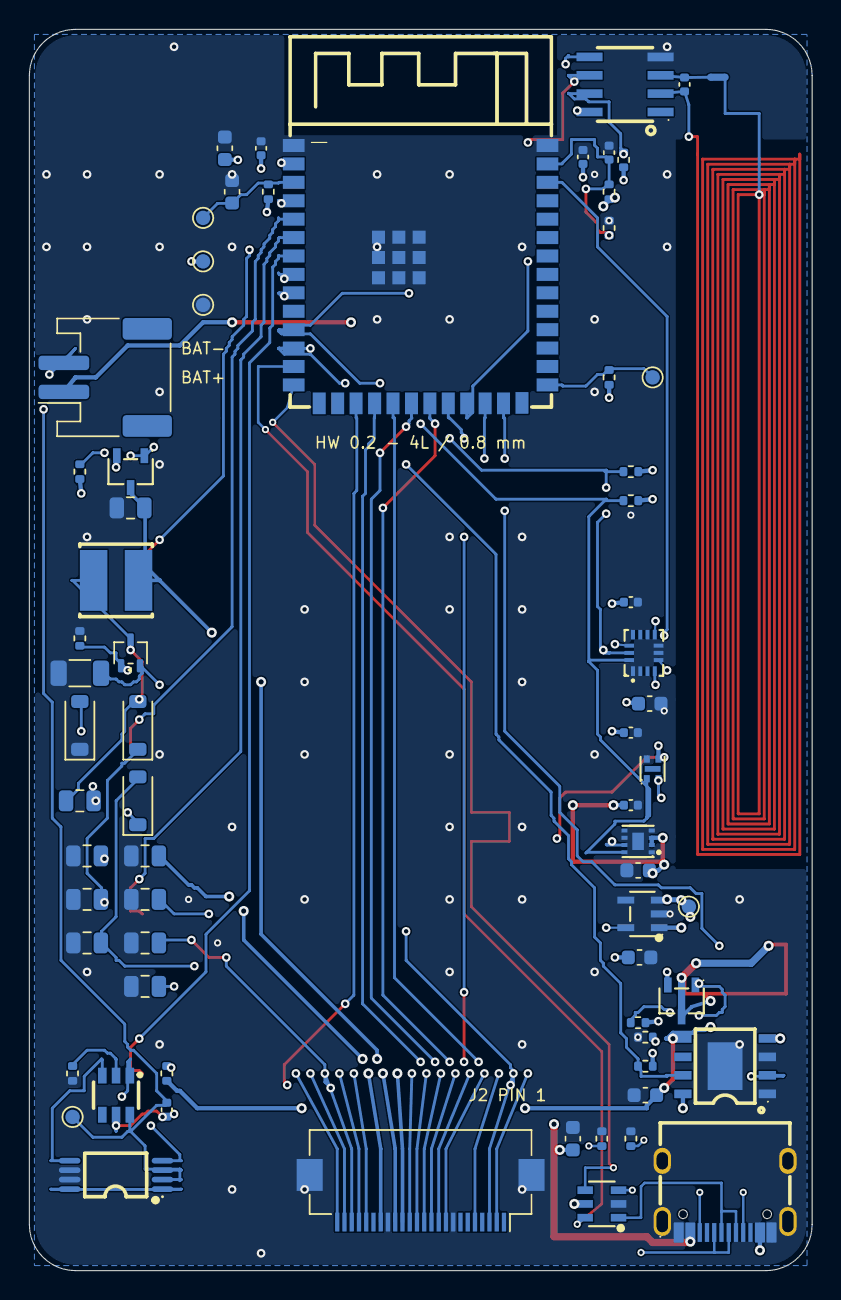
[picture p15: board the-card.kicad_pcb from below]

Board: 4 copper layers, 54.0 x 85.6 mm, 78 parts (68 on the bottom side), 53 nets.

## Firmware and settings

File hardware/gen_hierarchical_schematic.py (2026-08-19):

#!/usr/bin/env python3
"""Generate a deterministic, hand-laid-out single-page KiCad schematic.

`circuit.py` remains the electrical source of truth. This module only decides
how the already-built circuit is split across sheets and drawn. It deliberately
does not use SKiDL's force-directed schematic placer: this design is small
enough that an explicit signal-flow layout is clearer and produces stable diffs.

Run from `hardware/`:

    uv run python gen_hierarchical_schematic.py

The output is `the-card.kicad_sch`, an A2 landscape drawing divided into five
functional regions. All coordinates are on KiCad's 1.27 mm connection grid.
"""

from __future__ import annotations

import re
import uuid
from dataclasses import dataclass
from pathlib import Path

import circuit
from design_metadata import (
  DESIGN_VERSION,
  DNP_REFERENCES,
  NON_ASSEMBLY_REFERENCES,
  PROJECT_NAME,
)


HERE = Path(__file__).resolve().parent
LIBS = HERE / "libraries"
POWER_LIB = Path(
  "/Applications/KiCad/KiCad.app/Contents/SharedSupport/symbols/power.kicad_sym"
)
STANDARD_SYMBOL_DIR = Path(
  "/Applications/KiCad/KiCad.app/Contents/SharedSupport/symbols"
)
TITLE = "the-card - ESP32-S3 e-paper smart badge"
DATE = "2026-08-09"
GRID = 1.27
NAMESPACE = uuid.UUID("fc4df8d7-161d-494c-8bdb-f31f5ce3a8c0")

PASSIVE_SYMS = {"0402WGF1002TCE", "CL05B104KO5NNNC", "CL10A106KP8NNNC"}
STANDARD_SYMBOL_LIBS = {
  "Conn_01x02": "Connector_Generic",
  "D": "Device",
  "L": "Device",
  "Q_NMOS_GSD": "Transistor_FET",
  "TestPoint": "Connector",
}
SYMBOL_POWER_NETS = {"GND", "+3V3", "VBUS"}
CUSTOM_POWER_NETS = {"+BAT", "AUX_3V3", "EPD_VCI"}


def uid(*parts: object) -> str:
  """Return a stable UUID so regeneration produces reviewable diffs."""
  return str(uuid.uuid5(NAMESPACE, "::".join(str(part) for part in parts)))


def esc(value: object) -> str:
  return str(value).replace("\\", "\\\\").replace('"', '\\"')


def g(value: float) -> float:
  """Convert grid units to millimetres."""
  return round(value * GRID, 3)


def snap(value: float) -> float:
  return round(round(value / GRID) * GRID, 3)


def fmt(value: float) -> str:
  return f"{value:.3f}".rstrip("0").rstrip(".")


@dataclass(frozen=True)
class Placement:
  x: float
  y: float
  rotation: int = 0


@dataclass(frozen=True)
class SheetSpec:
  key: str
  refs: frozenset[str]
  placements: dict[str, Placement]
  notes: tuple[tuple[str, float, float, float], ...]
  passive_callouts: tuple[tuple[str, float, float, float], ...]


def p(x: float, y: float, rotation: int = 0) -> Placement:
  return Placement(g(x), g(y), rotation)


SHEETS = (
  SheetSpec(
    key="power_usb",
    refs=frozenset({
      "J1", "J3", "U10", "R_cc1", "R_cc2", "C_vbus",
      "U6", "R_prog", "R_chrg", "C_bat",
      "U7", "U8", "R_dvcc", "R_dvm", "C_dprot",
      "U9", "C_ldoi", "C_ldoo", "U5", "C_fg",
      "Q1", "R_q1g", "Q2", "R_q2g",
      "TP1", "TP2", "TP3", "TP4",
    }),
    placements={
      "J1": p(65, 50),
      "J3": p(20, 140),
      "U10": p(25, 50, 180),
      "R_cc1": p(47, 37),
      "R_cc2": p(47, 65),
      "C_vbus": p(112, 68, 270),
      "U6": p(125, 50),
      "R_prog": p(103, 50, 180),
      "R_chrg": p(148, 50, 180),
      "C_bat": p(138, 68, 270),
      "U9": p(180, 50),
      "C_ldoi": p(168, 68, 270),
      "C_ldoo": p(192, 68, 270),
      "U5": p(235, 50),
      "C_fg": p(218, 68, 270),
      "U7": p(75, 130, 180),
      # Rotate the dual MOSFET so its gate traces do not run through the
      # intervening source pins on either side of the symbol.
      "U8": p(105, 128, 90),
      "R_dvcc": p(48, 118),
      "R_dvm": p(92, 130, 180),
      # Both pins face outward: VDD above and BAT_NEG directly on the trunk.
      "C_dprot": p(58, 138, 270),
      "Q1": p(185, 130),
      "R_q1g": p(176, 116, 270),
      "Q2": p(225, 130),
      "R_q2g": p(216, 116, 270),
      "TP1": p(18, 148),
      "TP2": p(30, 148),
      "TP3": p(195, 112),
      "TP4": p(205, 112),
    },
    notes=(
      ("USB-C input, ESD, and charger", g(12), g(12), 1.8),
      ("3.3 V regulation and fuel gauge", g(165), g(12), 1.8),
      ("Cell protection", g(12), g(100), 1.8),
      ("Switched peripheral rails", g(165), g(94), 1.8),
    ),
    passive_callouts=(
      (
        "J1/U10 support: R5/R6 CC pull-downs; C5 USB input bulk",
        g(12), g(84), 1.0,
      ),
      (
        "U6 support: R7 charge-current set; R8 CHRG pull-up; C5/C6 bulk",
        g(88), g(84), 1.0,
      ),
      (
        "U9/U5 support: C8/C9 LDO stability; C10 fuel-gauge bypass",
        g(168), g(84), 1.0,
      ),
      (
        "U7/U8 support: R9 supply feed; R10 pack sense; C7 bypass",
        g(12), g(158), 1.0,
      ),
      (
        "Q1/Q2 support: R11/R12 gate pull-ups (rails default off)",
        g(165), g(103), 1.0,
      ),
    ),
  ),
  SheetSpec(
    key="mcu",
    refs=frozenset({
      "U1", "C_mcu1", "C_mcu2", "R_en", "C_en", "R_io0",
      "R_vbh", "R_vbl", "C_vb", "TP5", "TP6",
    }),
    placements={
      "U1": p(115, 70),
      # Draw the two supply capacitors as distinct parallel shunts, rather
      # than a close horizontal pair that can be mistaken for a series path.
      "C_mcu1": p(58, 43, 270),
      "C_mcu2": p(75, 43, 270),
      "R_en": p(87, 58, 270),
      # Keep the MCU's leftmost wiring inside its own visual column.
      "C_en": p(72, 70, 270),
      "R_io0": p(148, 82, 270),
      "R_vbh": p(145, 60, 270),
      "R_vbl": p(145, 68, 270),
      "C_vb": p(158, 68, 270),
      # Keep the EN test point left of U1's dense label fanout.
      "TP5": p(78, 80),
      "TP6": p(148, 96),
    },
    notes=(
      ("Controller, boot straps, decoupling, and battery ADC", g(12), g(12), 1.8),
      ("Named labels keep long inter-block connections readable.", g(12), g(20), 1.1),
    ),
    passive_callouts=(
      (
        "C1/C2 -> U1: 3V3 bypass + bulk; "
        "R1/C3 -> U1 EN: pull-up + startup timing",
        g(12), g(28), 1.0,
      ),
      (
        "R2 -> U1 IO0: boot pull-up; "
        "R3/R4/C4 -> U1 IO1: battery divider + filter",
        g(12), g(115), 1.0,
      ),
    ),
  ),
  SheetSpec(
    key="sensors_nfc",
    refs=frozenset({
      "U2", "C_nfc", "U3", "C_imu1", "C_imu2", "U4", "C_sht",
      "R_scl", "R_sda", "R_nfc_irq", "C_nfc_tune", "L2",
    }),
    placements={
      "U2": p(50, 45),
      "C_nfc": p(78, 45, 270),
      "R_nfc_irq": p(88, 58, 270),
      "L2": p(35, 45, 90),
      "C_nfc_tune": p(35, 58, 270),
      "U3": p(52, 96),
      "C_imu1": p(82, 84, 270),
      "C_imu2": p(96, 96, 270),
      "U4": p(125, 96),
      "C_sht": p(150, 96, 270),
      "R_scl": p(112, 38, 270),
      "R_sda": p(128, 38, 270),
    },
    notes=(
      ("NFC dynamic tag", g(12), g(12), 1.8),
      ("Motion and environmental sensors", g(12), g(75), 1.8),
      ("I2C pull-ups", g(105), g(12), 1.8),
    ),
    passive_callouts=(
      (
        "C11 -> U2: NFC bypass; R17 -> GPO pull-up; C29 -> RF trim (DNP)",
        g(12), g(22), 1.0,
      ),
      (
        "R13/R14 -> I2C bus U1-U5: SCL/SDA pull-ups",
        g(105), g(22), 1.0,
      ),
      (
        "C12/C13 -> U3: IMU bypass + bulk",
        g(12), g(122), 1.0,
      ),
      (
        "C14 -> U4: environmental-sensor bypass",
        g(105), g(122), 1.0,
      ),
    ),
  ),
  SheetSpec(
    key="epaper",
    refs=frozenset({
      "J2", "L1", "Q3", "D2", "D3", "D4", "R_epdg", "R_epds",
      "C_epd_in", "C_epd_pump", "C_epdvdd", "C_epd_vsh2",
      "C_epd_vsh1", "C_epd_vgh", "C_epd_vsl", "C_epd_vgl",
      "C_epd_vcom",
    }),
    placements={
      # Leave room for the connector value and right-facing net labels before
      # the page frame.
      "J2": p(150, 70),
      "L1": p(50, 58, 90),
      "Q3": p(72, 64),
      "D2": p(90, 32),
      "D3": p(90, 43),
      # Put the anode directly on EPD_SW and face the cathode toward EPD_VGH.
      "D4": p(94, 58, 180),
      "R_epdg": p(62, 82, 270),
      "R_epds": p(82, 82, 270),
      # C20 is the local EPD_VCI reservoir at L1's input.
      "C_epd_in": p(38, 72, 270),
      # Vertical orientation keeps the charge-pump and switch-node terminals
      # on opposite sides instead of routing one net through the capacitor.
      "C_epd_pump": p(72, 43, 270),
      # The five simple J2-to-capacitor rails sit around the connector. Their
      # GND terminals face away from J2 and their signal wires use nested,
      # non-crossing lanes.
      "C_epd_vsh2": p(128, 63, 180),
      "C_epdvdd": p(172, 86),
      "C_epd_vsh1": p(172, 94),
      "C_epd_vgh": p(112, 58),
      "C_epd_vsl": p(172, 102),
      "C_epd_vgl": p(112, 32),
      "C_epd_vcom": p(172, 110),
    },
    notes=(
      ("GDEY029T94 24-pin FPC interface", g(12), g(12), 1.8),
      ("Booster and boosted gate rails", g(35), g(22), 1.2),
      ("J2 panel connector and direct rail reservoirs", g(125), g(22), 1.2),
    ),
    passive_callouts=(
      (
        "C20/L1: VCI input; C21/D2-D4/Q3: boost conversion",
        g(35), g(112), 1.0,
      ),
      (
        "R15/R16: Q3 gate pull-down and current sense",
        g(35), g(120), 1.0,
      ),
      (
        "C22-C24/C26/C28: direct J2 rail reservoirs",
        g(125), g(118), 1.0,
      ),
      (
        "C25/C27: boosted VGH/VGL reservoirs",
        g(125), g(126), 1.0,
      ),
    ),
  ),
  SheetSpec(
    key="ui",
    refs=frozenset({
      "D1", "C_led", "SW1", "SW2", "SW3", "SW4",
      "C_btn1", "C_btn2", "C_btn3", "C_btn4",
    }),
    placements={
      "SW1": p(40, 55),
      "SW2": p(90, 55),
      "SW3": p(140, 55),
      "SW4": p(180, 55),
      # Offset the capacitors from the switches; the signal leg can then
      # dogleg around pin 3 instead of appearing to join its GND stub.
      "C_btn1": p(32, 67, 270),
      "C_btn2": p(82, 67, 270),
      "C_btn3": p(132, 67, 270),
      "C_btn4": p(172, 67, 270),
      "D1": p(125, 118),
      "C_led": p(88, 118, 270),
    },
    notes=(
      ("User buttons with hardware debounce", g(12), g(12), 1.8),
      ("Status LED", g(82), g(96), 1.8),
    ),
    passive_callouts=(
      (
        "C16-C19 -> SW1-SW4/U1: button debounce",
        g(12), g(22), 1.0,
      ),
      (
        "C15 -> D1: LED supply bypass",
        g(82), g(105), 1.0,
      ),
    ),
  ),
)

# Placement tables remain readable through circuit.py's semantic passive names,
# while generated KiCad references use conventional R1/C1 designators.
SHEETS = tuple(
  SheetSpec(
    key=sheet.key,
    refs=frozenset(circuit.physical_ref(ref) for ref in sheet.refs),
    placements={
      circuit.physical_ref(ref): placement
      for ref, placement in sheet.placements.items()
    },
    notes=sheet.notes,
    passive_callouts=sheet.passive_callouts,
  )
  for sheet in SHEETS
)

SHEET_BY_REF = {ref: sheet for sheet in SHEETS for ref in sheet.refs}

# Preserve each functional block's local placement and tile the blocks onto A2.
# Values are grid units and are applied before any pin or wire coordinates are
# calculated.
SINGLE_PAGE_OFFSETS = {
  "power_usb": (g(0), g(0)),
  # Start below the final power-section callout instead of sharing its band.
  "mcu": (g(130), g(145)),
  "sensors_nfc": (g(265), g(0)),
  "epaper": (g(270), g(165)),
  "ui": (g(0), g(165)),
}

# These widely separated or intentionally symbolic endpoints are clearer as
# repeated named stubs than as long wires.
LABEL_EACH_NETS = {
  ("sensors_nfc", "NFC_AC0"),
  ("sensors_nfc", "NFC_AC1"),
  ("sensors_nfc", "I2C_SCL"),
  ("sensors_nfc", "I2C_SDA"),
}

# Some named nets contain multiple compact circuits separated by enough space
# that one continuous wire would obscure the signal flow. Wire each compact
# cluster locally and emit one label for the cluster, instead of labeling every
# component pin. Endpoint keys are explicit so a circuit change cannot silently
# alter the drawing convention.
NET_LABEL_CLUSTERS = {
  # EPD_VCI crosses the power and e-paper regions. Keep the two J2 pins as
  # compact label stubs, but wire C20 directly to the L1 input locally.
  ("epaper", "EPD_VCI"): (
    (("J2", "15"),),
    (("J2", "16"),),
    (("L1", "1"), ("C20", "1")),
  ),
  ("epaper", "EPD_GDR"): (
    (("J2", "2"),),
    (("Q3", "1"), ("R15", "1")),
  ),
  ("epaper", "EPD_RESE"): (
    (("J2", "3"),),
    (("Q3", "2"), ("R16", "1")),
  ),
  ("epaper", "EPD_VGH"): (
    (("J2", "21"),),
    (("D4", "1"), ("C25", "1")),
  ),
  ("epaper", "EPD_VGL"): (
    (("J2", "23"),),
    (("D2", "2"), ("C27", "1")),
  ),
}

# A clustered net normally derives its label direction from the cluster's first
# component pin. These free-space anchors keep selected labels horizontal on an
# existing local wire. Coordinates are relative to the functional region.
CLUSTER_LABEL_ANCHORS = {
  ("epaper", "EPD_RESE", ("Q3", "2")): (g(78), g(68)),
}

# Visible property locations that need to follow the schematic's local
# functional layout rather than the generic symbol bounds. Coordinates are
# offsets from the component centre in grid units.
PROPERTY_LAYOUT = {
  "C20": ((-6, -1, 270), (-6, 2, 270)),
  "C21": ((-6, -1, 270), (-6, 2, 270)),
  "L1": ((0, -4, 90), (0, 4, 90)),
  "Q3": ((0, -9, 0), (0, 9, 0)),
  "J2": ((0, -17, 0), (0, 18, 0)),
}

# Most parts use the standard 1.2 mm reference and 1.0 mm value sizes. J2 keeps
# the standard reference hierarchy while its long centred part number is
# reduced to fit beside the surrounding net labels.
PROPERTY_FONT_SIZES = {
  "J2": (1.2, 0.8),
}

# The 8205A exposes its common drain on two opposite pins. Repeated labels
# communicate that internal node without drawing a misleading wire through the body.
LABEL_EACH_LOCAL_NETS = {("power_usb", "FET_DRAIN")}

# Explicit trunks keep the interleaved reversible USB-C data pins readable.
TRUNK_ROUTES = {
  ("power_usb", "N$6"): ("horizontal", g(72)),
  ("power_usb", "N$7"): ("horizontal", g(28)),
  # Keep the boost switch node on D4's anode so the diode reads left-to-right.
  ("epaper", "EPD_SW"): ("horizontal", g(58)),
}

# Two-terminal nets normally use a single orthogonal corner. These nets need a
# third segment so that the route does not pass through unrelated symbol pins.
# The coordinate is the lane used between the two endpoints.
TWO_PIN_DOGLEG_ROUTES = {
  ("power_usb", "N$10"): ("horizontal", g(146)),
  ("power_usb", "N$11"): ("horizontal", g(113)),
  ("ui", "BTN_UP"): ("vertical", g(28)),
  ("ui", "BTN_DOWN"): ("vertical", g(78)),
  ("ui", "BTN_SEL"): ("vertical", g(128)),
  ("ui", "BTN_MENU"): ("vertical", g(168)),
  # Fan the four adjacent right-side J2 rails into a spaced capacitor bank.
  # Decreasing lane X while increasing capacitor Y keeps the routes nested.
  ("epaper", "EPD_VDD_CORE"): ("vertical", g(168)),
  ("epaper", "EPD_VSH1"): ("vertical", g(166)),
  ("epaper", "EPD_VSL"): ("vertical", g(164)),
  ("epaper", "EPD_VCOM"): ("vertical", g(162)),
}

# Prefer these pins when a multi-pin local branch also needs a global label.
LABEL_PIN = {
  ("power_usb", "~CHRG"): ("U6", "7"),
  ("power_usb", "PWR_AUX"): ("Q1", "1"),
  ("power_usb", "EPD_PWR_EN"): ("Q2", "1"),
  ("ui", "BTN_UP"): ("SW1", "1"),
  ("ui", "BTN_DOWN"): ("SW2", "1"),
  ("ui", "BTN_SEL"): ("SW3", "1"),
  ("ui", "BTN_MENU"): ("SW4", "1"),
}

# Put the visible label branch on the existing local route, away from component
# pins. These are true three-way electrical junctions and therefore get dots.
LABEL_JUNCTION_POINTS = {
  ("power_usb", "PWR_AUX"): (g(176), g(130)),
  ("power_usb", "EPD_PWR_EN"): (g(216), g(130)),
  ("ui", "BTN_UP"): (g(28), g(53)),
  ("ui", "BTN_DOWN"): (g(78), g(53)),
  ("ui", "BTN_SEL"): (g(128), g(53)),
  ("ui", "BTN_MENU"): (g(168), g(53)),
}


def extract_symbols(path: Path) -> dict[str, str]:
  """Extract top-level symbol blocks from a KiCad symbol library."""
  text = path.read_text()
  symbols: dict[str, str] = {}
  cursor = 0
  while True:
    start = text.find('(symbol "', cursor)
    if start < 0:
      return symbols
    q1 = text.find('"', start)
    q2 = text.find('"', q1 + 1)
    name = text[q1 + 1:q2]
    depth = 0
    end = start
    while end < len(text):
      if text[end] == "(":
        depth += 1
      elif text[end] == ")":
        depth -= 1
        if depth == 0:
          break
      end += 1
    if not re.search(r"_\d+_\d+$", name):
      symbols[name] = text[start:end + 1]
    cursor = end + 1


SYMBOLS: dict[str, str] = {}
for library_filename in ("passives.kicad_sym", "the-card.kicad_sym"):
  SYMBOLS.update(extract_symbols(LIBS / library_filename))
for library_name in sorted(set(STANDARD_SYMBOL_LIBS.values())):
  SYMBOLS.update(extract_symbols(STANDARD_SYMBOL_DIR / f"{library_name}.kicad_sym"))
POWER_SYMBOLS = extract_symbols(POWER_LIB)


def symbol_field(symbol_name: str, field_name: str) -> str:
  block = SYMBOLS[symbol_name]
  match = re.search(
    rf'\(property\s+"{re.escape(field_name)}"\s+"([^"]*)"',
    block,
    re.MULTILINE,
  )
  return match.group(1) if match else ""


def power_block(net_name: str) -> str:
  """Return an embedded power symbol, synthesizing custom rail symbols."""
  if net_name == "GND":
    # Use KiCad's familiar three-bar earth graphic. A hidden GND global label at
    # the same anchor retains the circuit's electrical net name.
    symbol_name = "Earth"
    block = POWER_SYMBOLS[symbol_name]
  elif net_name in POWER_SYMBOLS:
    symbol_name = net_name
    block = POWER_SYMBOLS[net_name]
  else:
    symbol_name = net_name
    block = POWER_SYMBOLS["+3V3"].replace("+3V3", net_name)
  block = block.replace(
    f'(symbol "{symbol_name}"', f'(symbol "power:{symbol_name}"', 1
  )
  return re.sub(r"\(pin\s+power_in\s+line", "(pin passive line", block)


def passive_symbol_block(symbol_name: str, library: str) -> str:
  block = SYMBOLS[symbol_name].replace(
    f'(symbol "{symbol_name}"', f'(symbol "{library}:{symbol_name}"', 1
  )
  return re.sub(r"\(pin\s+[^\s()]+\s+line", "(pin passive line", block)


def rot_point(x: float, y: float, rotation: int) -> tuple[float, float]:
  rotation %= 360
  if rotation == 0:
    return x, y
  if rotation == 90:
    return y, -x
  if rotation == 180:
    return -x, -y
  if rotation == 270:
    return -y, x
  raise ValueError(f"Unsupported rotation: {rotation}")


def pin_position(part: dict, pin: dict) -> tuple[float, float]:
  local_x, local_y = rot_point(pin["x"], -pin["y"], part["rotation"])
  return snap(part["x"] + local_x), snap(part["y"] + local_y)


def outward_direction(
  part: dict,
  point: tuple[float, float],
  pin: dict | None = None,
) -> str:
  if pin is not None:
    total_rotation = (pin["rotation"] + part["rotation"]) % 360
    return {
      0: "left",
      90: "down",
      180: "right",
      270: "up",
    }[total_rotation]
  dx = point[0] - part["x"]
  dy = point[1] - part["y"]
  if abs(dx) >= abs(dy):
    return "right" if dx >= 0 else "left"
  return "down" if dy >= 0 else "up"


def direction_vector(direction: str, distance: float) -> tuple[float, float]:
  return {
    "right": (distance, 0.0),
    "left": (-distance, 0.0),
    "down": (0.0, distance),
    "up": (0.0, -distance),
  }[direction]


def wire(seed: str, start: tuple[float, float], end: tuple[float, float]) -> str:
  if start == end:
    raise ValueError(f"Zero-length wire for {seed}: {start}")
  return (
    "\t(wire\n"
    f"\t\t(pts (xy {fmt(start[0])} {fmt(start[1])}) "
    f"(xy {fmt(end[0])} {fmt(end[1])}))\n"
    "\t\t(stroke (width 0) (type default))\n"
    f"\t\t(uuid \"{uid('wire', seed, *start, *end)}\")\n"
    "\t)"
  )


def wire_path(
  seed: str,
  points: list[tuple[float, float]],
) -> list[str]:
  """Emit the non-zero orthogonal segments in a route."""
  result = []
  for start, end in zip(points, points[1:]):
    if start != end:
      result.append(wire(seed, start, end))
  return result


def point_on_segment(
  point: tuple[float, float],
  segment: tuple[tuple[float, float], tuple[float, float]],
) -> bool:
  """Return whether a point lies on an orthogonal wire segment."""
  start, end = segment
  if start[0] == end[0] == point[0]:
    return min(start[1], end[1]) <= point[1] <= max(start[1], end[1])
  if start[1] == end[1] == point[1]:
    return min(start[0], end[0]) <= point[0] <= max(start[0], end[0])
  return False


def junction(seed: str, point: tuple[float, float]) -> str:
  return (
    "\t(junction\n"
    f"\t\t(at {fmt(point[0])} {fmt(point[1])})\n"
    "\t\t(diameter 0)\n"
    "\t\t(color 0 0 0 0)\n"
    f"\t\t(uuid \"{uid('junction', seed, *point)}\")\n"
    "\t)"
  )
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

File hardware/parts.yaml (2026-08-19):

# the-card — Schematic Parts Manifest
# Source-of-truth for schematic generation.
#   - supplier-specific parts with an `lcsc` id are fetched via `easyeda2kicad`
#     into hardware/libraries/ (symbol + footprint + 3D).
#   - `assembly_parts` assigns exact purchasable parts to stock/project symbols
#     without fetching additional EasyEDA libraries.
#   - common passives reuse fetched project templates; bring-up test points use
#     KiCad stock symbols and footprints.
#   - The bare e-ink panel is represented by a 24-pin FPC connector; its required
#     SSD1680 booster and high-voltage capacitors are populated on our PCB.
# Refdes follow the schematic. Update here = update the schematic.

project: the-card
eda: kicad
kicad_version: "10.0"
libs_output: hardware/libraries/
jlcpcb_classification_checked: "2026-08-11"

# ─────────────────────────────────────────────────────────────────────────────
# Supplier-specific parts  (fetch from LCSC via easyeda2kicad)
# ─────────────────────────────────────────────────────────────────────────────
lcsc_parts:
  - ref: U1
    name: ESP32-S3-WROOM-1-N16R8
    lcsc: C2913202
    source_hint: JLCPCB Extended
    role: MCU (WiFi+BLE, 16MB Flash, 8MB Octal PSRAM)
  - ref: U2
    name: ST25DV04KC-IE8S3
    lcsc: C5221752
    source_hint: JLCPCB Extended
    role: NFC dynamic tag with GPO wake (V_EH left unconnected)
  - ref: U3
    name: LSM6DSOTR
    lcsc: C2655100
    source_hint: JLCPCB Extended
    role: 6-axis IMU
  - ref: U4
    name: SHT40-BD1B-R2
    lcsc: C7461849
    source_hint: JLCPCB Extended
    role: Temp / Humidity
  - ref: U5
    name: MAX17048G+T10
    lcsc: C2682616
    source_hint: JLCPCB Extended
    role: Li-ion fuel gauge (ModelGauge)
  - ref: U6
    name: TP4056
    lcsc: C382139
    source_hint: JLCPCB Extended
    role: Li-ion charger (configured for approximately 500mA)
  - ref: U7
    name: DW01A
    lcsc: C18164398
    source_hint: JLCPCB Extended
    role: Battery protection IC
  - ref: U8
    name: FS8205A
    lcsc: C16052
    source_hint: JLCPCB Extended
    role: Dual N-MOSFET symbol and footprint template (protection)
    note: Assembly uses the pin-compatible HXY 8205A selected below.
  - ref: U9
    name: ME6211C33M5G
    lcsc: C82942
    source_hint: JLCPCB Extended
    role: LDO 3.3V / 500mA
  - ref: U10
    name: USBLC6-2SC6
    lcsc: C7519
    source_hint: JLCPCB Extended
    role: USB ESD protection  # also exists in KiCad Power_Protection
  - ref: Q1
    name: SI2301
    lcsc: C10487
    source_hint: JLCPCB Basic
    role: P-MOSFET — AUX LED rail and e-paper VCI gates  # also in Transistor_FET
    qty: 2                     # Q1, Q2
  - ref: D1
    name: WS2812B-Mini
    lcsc: C527089
    source_hint: JLCPCB Extended
    role: RGB status LED (on AUX branch rail)
  - ref: J1
    name: TYPE-C-31-M-12
    lcsc: C165948
    source_hint: JLCPCB Extended
    role: USB-C receptacle (6-pin, power+data)
  - ref: SW
    name: TS-1187A
    lcsc: C318884
    source_hint: JLCPCB Basic
    role: Tactile button (watch-style)
    qty: 4                     # SW1 UP, SW2 DOWN, SW3 SEL, SW4 MENU
  - ref: J2
    name: Hirose FH12-24S-0.5SH(55)
    lcsc: distributor
    source_hint: distributor
    role: E-ink panel FPC connector (24 signal + 2 mount pads)
    note: bottom-contact ZIF, 0.5 mm pitch, for 0.30 mm FPC
  - ref: J3
    name: S2B-PH-SM4-TB(LF)(SN)
    lcsc: C295747
    source_hint: JLCPCB Extended
    role: 1S battery connector (pin 1 +BAT, pin 2 BAT_NEG)
    footprint: "Connector_JST:JST_PH_S2B-PH-SM4-TB_1x02-1MP_P2.00mm_Horizontal"
    note: Right-angle SMT JST-PH. Battery cable polarity is not standardized; inspect the actual pack.
  - ref: L1
    name: XRNR5020-47uH/M
    lcsc: C5339697
    source_hint: JLCPCB Extended
    role: E-paper boost inductor, 47uH, 750mA rated / 770mA saturation
    footprint: "the-card:IND-SMD_L5.0-W5.0_XRNR5020"

# ─────────────────────────────────────────────────────────────────────────────
# Passive templates — fetched into libraries/passives.kicad_sym (symbol only;
# footprints are assigned in circuit.py). One symbol reused across many values.
# ─────────────────────────────────────────────────────────────────────────────
passive_templates:
  - lcsc: C25744
    symbol: 0402WGF1002TCE
    role: 0402 resistor (reused for all R)
  - lcsc: C1525
    symbol: CL05B104KO5NNNC
    role: 0402 capacitor (reused for all 0402 C)
  - lcsc: C19702
    symbol: CL10A106KP8NNNC
    role: 0603 capacitor (reused for all 0603 C)
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

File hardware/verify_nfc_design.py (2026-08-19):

#!/usr/bin/env python3
"""Verify the v0.2.0 NFC schematic and PCB invariants.

The KiCad DRC remains authoritative. This checker adds focused, readable
failures for the electrical connections that made the GPO usable and for any
foreign copper that enters the antenna's all-layer quiet area.
"""

from __future__ import annotations

import argparse
from collections import Counter
from dataclasses import dataclass
from itertools import pairwise
import math
from pathlib import Path
import re
import subprocess
import tempfile
import xml.etree.ElementTree as ET

from nfc_antenna import (
  ANTENNA_NETS,
  QUIET_AREA,
  RULE_AREA_NAME,
  TRACK_WIDTH_MM,
  global_rectangle,
  spiral_points,
)
from verify_schematic import find_kicad_cli


HERE = Path(__file__).resolve().parent
DEFAULT_SCHEMATIC = HERE / "the-card.kicad_sch"
DEFAULT_BOARD = HERE / "the-card.kicad_pcb"
COPPER_LAYERS = frozenset({"F.Cu", "In1.Cu", "In2.Cu", "B.Cu"})
Node = tuple[str, str]
Point = tuple[float, float]

EXPECTED_EXACT_NETS: dict[str, frozenset[Node]] = {
  "NFC_IRQ": frozenset({("R17", "2"), ("U1", "23"), ("U2", "7")}),
  "NFC_AC0": frozenset({("C29", "1"), ("L2", "1"), ("U2", "2")}),
  "NFC_AC1": frozenset({("C29", "2"), ("L2", "2"), ("U2", "3")}),
}
EXPECTED_SCHEMATIC_COMPONENTS = {
  "U2": {
    "value": "ST25DV04KC-IE8S3",
    "footprint": "the-card:SO-8_L4.9-W3.9-P1.27-LS6.0-BL",
  },
  "R17": {
    "value": "10k",
    "footprint": "Resistor_SMD:R_0402_1005Metric",
  },
  "C29": {
    "value": "DNP 0-22pF C0G/NP0",
    "footprint": "Capacitor_SMD:C_0402_1005Metric",
    "datasheet": "",
    "properties": frozenset({"dnp"}),
  },
  "L2": {
    "value": "PCB NFC antenna",
    "footprint": "NetTie:NetTie-2_SMD_Pad0.5mm",
    "properties": frozenset({"exclude_from_bom"}),
  },
}
EXPECTED_BOARD_COMPONENTS = {
  "U2": {
    "value": "ST25DV04KC-IE8S3",
    "footprint": "the-card:SO-8_L4.9-W3.9-P1.27-LS6.0-BL",
    "attributes": frozenset(),
  },
  "R17": {
    "value": "10k",
    "footprint": "Resistor_SMD:R_0402_1005Metric",
    "attributes": frozenset(),
  },
  "C29": {
    "value": "DNP 0-22pF C0G/NP0",
    "footprint": "Capacitor_SMD:C_0402_1005Metric",
    "attributes": frozenset({"dnp"}),
    "properties": {"Datasheet": ""},
  },
  "L2": {
    "value": "PCB NFC antenna",
    "footprint": "NetTie:NetTie-2_SMD_Pad0.5mm",
    "attributes": frozenset({"exclude_from_bom", "exclude_from_pos_files"}),
    "net_tie_pad_groups": "1, 2",
    "bridge_layer": "B.Cu",
    "bridge_polygon": frozenset({
      (-0.5, -0.25),
      (-0.5, 0.25),
      (0.5, -0.25),
      (0.5, 0.25),
    }),
  },
}


@dataclass(frozen=True)
class Bounds:
  left: float
  top: float
  right: float
  bottom: float

  def expanded(self, amount: float) -> "Bounds":
    return Bounds(
      self.left - amount,
      self.top - amount,
      self.right + amount,
      self.bottom + amount,
    )

  def inset(self, amount: float) -> "Bounds":
    return self.expanded(-amount)


def quiet_bounds() -> Bounds:
  quiet = global_rectangle(QUIET_AREA)
  return Bounds(
    quiet.x,
    quiet.y,
    quiet.x + quiet.width,
    quiet.y + quiet.height,
  )


def export_netlist_xml(
  schematic: Path,
  kicad_cli: Path | None = None,
) -> ET.Element:
  executable = find_kicad_cli(kicad_cli)
  with tempfile.TemporaryDirectory(prefix="the-card-nfc-") as temp_dir:
    xml_path = Path(temp_dir) / "schematic.xml"
    subprocess.run(
      [
        executable,
        "sch",
        "export",
        "netlist",
        "--format",
        "kicadxml",
        "--output",
        str(xml_path),
        str(schematic),
      ],
      check=True,
    )
    return ET.parse(xml_path).getroot()


def net_nodes(root: ET.Element) -> dict[str, frozenset[Node]]:
  return {
    net.attrib["name"]: frozenset(
      (node.attrib["ref"], node.attrib["pin"])
      for node in net.findall("node")
    )
    for net in root.findall("./nets/net")
  }


def _schematic_component_problems(root: ET.Element) -> list[str]:
  components = {
    component.attrib["ref"]: component
    for component in root.findall("./components/comp")
  }
  problems: list[str] = []
  for reference, expected in EXPECTED_SCHEMATIC_COMPONENTS.items():
    component = components.get(reference)
    if component is None:
      problems.append(f"{reference}: missing NFC component metadata")
      continue
    for field in ("value", "footprint", "datasheet"):
      if field not in expected:
        continue
      # KiCad omits an unassigned datasheet from exported XML, so absence and
      # an empty element both express the reviewed "no selected part" intent.
      actual = component.findtext(field) or ""
      if actual != expected[field]:
        problems.append(
          f"{reference}: expected {field}={expected[field]!r}, "
          f"actual={actual!r}"
        )
    properties = {
      prop.attrib["name"]
      for prop in component.findall("property")
    }
    missing_properties = sorted(expected.get("properties", set()) - properties)
    if missing_properties:
      problems.append(
        f"{reference}: missing properties={missing_properties}"
      )
  return problems


def schematic_problems(root: ET.Element) -> list[str]:
  nets = net_nodes(root)
  problems = _schematic_component_problems(root)
  for name, expected in EXPECTED_EXACT_NETS.items():
    actual = nets.get(name, frozenset())
    if actual != expected:
      problems.append(
        f"{name}: expected={sorted(expected)}, actual={sorted(actual)}"
      )

  power_nodes = nets.get("+3V3", frozenset())
  if ("R17", "1") not in power_nodes:
    problems.append("R17.1 must connect the NFC GPO pull-up to +3V3")

  gpio3_nets = [
    name for name, nodes in nets.items()
    if ("U1", "15") in nodes
  ]
  if not gpio3_nets:
    problems.append("U1.15 / GPIO3 is absent from the exported netlist")
  elif any(not name.startswith("unconnected-") for name in gpio3_nets):
    problems.append(
      "U1.15 / GPIO3 must remain unconnected, found "
      f"{sorted(gpio3_nets)}"
    )
  return problems


def _balanced_form(text: str, start: int) -> str:
  depth = 0
  quoted = False
  escaped = False
  for index in range(start, len(text)):
    character = text[index]
    if quoted:
      if escaped:
        escaped = False
      elif character == "\\":
        escaped = True
      elif character == '"':
        quoted = False
      continue
    if character == '"':
      quoted = True
    elif character == "(":
      depth += 1
    elif character == ")":
      depth -= 1
      if depth == 0:
        return text[start:index + 1]
  raise ValueError(f"unterminated S-expression at byte {start}")
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

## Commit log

2026-08-05 Initial commit: project docs, MIT license, repo scaffold
    ESP32-S3 based e-paper smart badge (DIY/learning platform).
    - System architecture: block diagram, subsystem design, GPIO pin map
    - BOM with LCSC part numbers and landed-cost analysis
    - State-based power budget and battery-life scenarios
    - MIT License; scaffold hardware/ firmware/ mechanical/ for upcoming work
2026-08-05 fix(bom): correct LCSC part numbers verified against LCSC
    LSM6DSO C967483 -> C2655100
    USBLC6 C7936 -> C7519
    DW01A C142001 -> C18164398
    FS8205A C32253 -> C16052
    WS2812B C5275773-> C527089
    Caught by validating the BOM through easyeda2kicad.
2026-08-05 build(hardware): add uv KiCad toolchain + LCSC parts manifest
    - uv project (hardware/) with skidl + easyeda2kicad, pinned via uv.lock
    - parts.yaml: single source of truth for parts/LCSC#/nets/passives
    - scripts/fetch_libs.sh: regenerates libraries/ from parts.yaml (gitignored)
    - hardware/README.md: setup & workflow notes
2026-08-05 feat(hardware): SKiDL schematic -> KiCad netlist (49 parts, ERC clean)
    circuit.py captures the full electrical design in code:
    - ESP32-S3 MCU, USB-C+ESD, TP4056 charger, DW01A+FS8205A protection,
    ME6211 LDO, MAX17048 fuel gauge, ST25DV04KC NFC, LSM6DSO IMU,
    SHT40, WS2812 LED, 2x SI2301 power gates, 4x buttons, e-ink FPC
    - power muxing: switchable AUX rail (Q1) + e-ink VDD gate (Q2)
    - 0 ERC errors; designators U1-U10/Q1-Q2/D1/J1-J2/SW1-4/R*/C*
    Pipeline is reproducible from parts.yaml:
    fetch_libs.sh -> libraries/{the-card,passives}.kicad_sym
    circuit.py -> the-card.net (KiCad PCBNEW import)
    parts.yaml: add passive_templates (R/C), FPC connector C6081230.
    Note GPIO33/34 unavailable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
    [parts.yaml]
2026-08-05 docs: add PROGRESS.md — status, components, roadmap
2026-08-05 fix(schematic): resolve VERIFY items against datasheets
    DW01A+FS8205A: pin mapping confirmed (EasyEDA DOUT/VM/COUT = HMSEMI DO/CS/CO);
    added 3 missing required parts — R1 470R (VCC<-B+), R2 2K (VM<-P-), C1 100nF.
    Gate assignment COUT->G1 / DOUT->G2, S1=B- / S2=P- verified.
    ST25DV04KC: SO-8 pinout matches symbol; internal tuning cap 28.5pF -> antenna
    on AC0/AC1 with no external cap.
    GDEY029T94: real 24-pin FFC pinout (Good Display §5) — prior 8-signal mapping
    was wrong. Rewired SPI to pins 9-14, power 15-17, BS1=GND (4-wire SPI), added
    VDD core bypass; booster/HV rails passed through (panel-side).
    ERC still 0 errors; now 53 components.
    [parts.yaml]
2026-08-05 docs(hardware): complete datasheet archive (16 parts + SSD1680 + ESP32-S3 chip)
    All actives/connectors now have a local PDF, sourced via mirrors that allow
    scripted fetch (LCSC, Farnell, DigiKey, SparkFun/Adafruit CDNs) since st.com /
    espressif.com block curl. README updated to all-local index.
2026-08-05 docs+verify: cross-check all pinouts against datasheets (no errors)
    Verified every active part's pinout vs the archived datasheets (pypdf extract):
    USBLC6-2, TP4056, MAX17048, LSM6DSO, ME6211, SI2301 (1=G/2=S/3=D), SHT40
    (1=SDA/2=SCL/3=VDD/4=VSS) — all match the easyeda symbols, no wiring errors.
    Note: TP4056 RPROG 1.2k -> ~0.83A on TPOWER chip (healthy 0.83C).
    Add pypdf as dev dep; gitignore hardware/.verify/ extractions.
2026-08-05 feat(hardware): KiCad 10 project scaffold for manual schematic capture
    - the-card.kicad_pro (from KiCad template, default settings)
    - the-card.kicad_sch (empty, kicad-cli ERC clean)
    - sym-lib-table/fp-lib-table register the-card + passives libraries (KIPRJMOD-relative)
    - SCHEMATIC-GUIDE.md: 5-sheet page-by-page drawing plan mirroring circuit.py
    skidl auto-schematic too slow for 53 parts -> manual capture in eeschema.
    [the-card.kicad_sch]
2026-08-05 chore: gitignore KiCad local project settings (*.kicad_prl)
2026-08-05 feat(hardware): generate the-card.kicad_sch directly from circuit.py
    gen_schematic.py builds the KiCad schematic in code (no GUI, no skidl auto-layout):
    - embeds symbol defs from our .kicad_sym libraries
    - places all 53 parts on a 1.27mm grid
    - net-labels every pin (skidl pin coords; Y negated vs KiCad)
    - marks intentionally-unused pins with no_connect
    - sets embedded pins to passive type (easyeda mistypes them) for clean ERC
    Result: the-card.kicad_sch loads in KiCad 10, ERC = 0 errors / 18 expected
    warnings (single-pin pass-through nets: NFC antenna, e-ink booster, motor).
    [the-card.kicad_sch]
2026-08-05 feat(hardware): v2 schematic gen — subsystem grouping + power symbols
    gen_schematic.py now:
    - groups parts into 5 labelled bands (POWER/MCU/DISPLAY/SENSORS/UI)
    - uses real KiCad power symbols (GND/+3V3/+BAT/VBUS/AUX_3V3/EPD_VDD) from the
    installed power.kicad_sym, with one PWR_FLAG per rail (power_out pin)
    - collision-aware placement (no cross-net pin-endpoint coincidences)
    - snaps to the 1.27 mm grid
    ERC: 0 errors (41 expected warnings: custom power symbols not in stock lib +
    single-pin pass-through nets). Renders to PDF.
    [the-card.kicad_sch]
2026-08-05 feat(hardware): v3 schematic — hand-crafted placement + local wires
    Replaces the uniform grid with a hand-designed layout: power chain top-left,
    MCU centre, I²C sensors on the left, e-ink/LED below, buttons at the bottom,
    decoupling caps against their ICs. Keeps KiCad power symbols + PWR_FLAG rails,
    net labels for MCU-fanout signals (correct for an MCU board), and direct wires
    for the few close 2-pin signal nets. ERC: 0 errors.
    [the-card.kicad_sch]
2026-08-05 feat(hardware): v4 schematic — pin-cluster placement, 13 direct wires
    Peripherals placed on the MCU side where their signal pins are:
    SPI bus (6 wires) below · buttons (4 wires) + USB (2) + LED (1) on left/bottom.
    Point-to-point nets become short L-wires; shared buses (I2C) stay labels.
    ERC: 0 errors (44 expected warnings).
    [the-card.kicad_sch]
2026-08-05 fix(hardware): v3.1 — hand-crafted layout + 13 wires (v3 placement, WIRE_MAX=120)
    Reverts to v3's hand-crafted placement (signal-flow, not pin-cluster auto-placement)
    but extends the 2-pin wire threshold to 120 mm, capturing 13 direct L-wires
    (SPI bus, buttons, USB, LED, etc.) while keeping the proven layout. ERC: 0 errors.
    [the-card.kicad_sch]
2026-08-06 fix(hardware): improved placement — USB near MCU, sensors hug I2C, caps on ICs
    - USB-C + ESD moved from power area to MCU left side (near USB_DM/DP pins)
    - Sensors shifted right to ~x310 (close to MCU I2C pins at ~x398)
    - Buttons raised from y=320 to y=385 (closer to BTN pin row)
    - Decoupling caps placed directly above their ICs (C_mcu1/2 at y=152, U1 at y=220)
    - Collision avoidance restored (prevents PWR_FLAG pin_to_pin)
    ERC: 0 errors, 13 wires.
    [the-card.kicad_sch]
2026-08-09 feat(hardware): add single-page schematic layout
    [the-card.kicad_sch]
2026-08-09 fix(hardware): correct ground symbol orientation
    [the-card.kicad_sch]
2026-08-09 feat(hardware): prepare schematic for pcb layout
    [the-card.kicad_sch]
2026-08-09 fix(hardware): correct display FPC connector
    [the-card.kicad_sch]
2026-08-09 feat(hardware): add initial pcb placement
    [the-card.kicad_pcb]
2026-08-09 feat(hardware): route pcb layout
    [the-card.kicad_pcb]
2026-08-10 fix(hardware): harden design for fabrication
    [the-card.kicad_pcb, the-card.kicad_sch]
2026-08-10 feat(hardware): embed pcb layer reference views
    [the-card.kicad_pcb]
2026-08-10 feat(hardware): add fabrication release workflow
    [the-card.kicad_pcb, the-card.kicad_sch]
2026-08-10 feat(hardware): upgrade MCU memory variant
    [the-card.kicad_pcb, the-card.kicad_sch]
2026-08-10 fix(hardware): source SMT battery connector and inductor
    [the-card.kicad_pcb, the-card.kicad_sch]
2026-08-11 fix(hardware): assign fabrication-ready BOM parts
    [the-card.kicad_pcb, the-card.kicad_sch]
2026-08-11 fix(hardware): replace unavailable U8 and R4 parts
    [parts.yaml]
2026-08-11 fix(hardware): align U8 fabrication metadata
    [the-card.kicad_pcb, the-card.kicad_sch]
2026-08-11 feat(hardware): add JLC assembly CSV exports
2026-08-11 chore(hardware): record JLCPCB assembly classes
2026-08-11 feat(hardware): annotate passive relationships
    [the-card.kicad_sch]
2026-08-12 feat(hardware): group schematic support passives
    [the-card.kicad_sch]
2026-08-12 refactor(hardware): collapse local schematic labels
    [the-card.kicad_sch]
2026-08-12 fix(hardware): clarify schematic routing
    [the-card.kicad_sch]
2026-08-12 refactor(hardware): improve schematic placement
    [the-card.kicad_sch]
2026-08-12 fix(hardware): improve schematic section spacing
    [the-card.kicad_sch]
2026-08-12 refactor(hardware): clarify schematic component groups
    [the-card.kicad_sch]
2026-08-12 fix(hardware): refine schematic property placement
    [the-card.kicad_sch]
2026-08-13 fix(hardware): align e-paper schematic labels
    [the-card.kicad_sch]
2026-08-15 fix(hardware): restore schematic PCB parity
    [the-card.kicad_pcb, the-card.kicad_sch]
2026-08-18 fix(ci): allow actions in KiCad container
2026-08-18 fix(ci): include standard KiCad libraries
2026-08-18 fix(ci): use KiCad image configuration
2026-08-18 feat(hardware): generate versioned output bundles
    [the-card.kicad_pcb, the-card.kicad_sch]
2026-08-18 fix(hardware): enforce semantic release versions
    [test_release_manifest.py]
2026-08-18 fix(hardware): neutralize scripting in PDF outputs
    [test_release_fabrication.py]
2026-08-18 feat(website): publish hardware release experience
    [bom.csv, placements.csv, positions.csv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]
2026-08-19 chore(hardware): normalize KiCad project metadata
2026-08-19 fix(hardware): redesign NFC interface and antenna
    [the-card.kicad_pcb, the-card.kicad_sch]
2026-08-19 refactor(hardware): unify design versioning
    [the-card.kicad_pcb, the-card.kicad_sch]
2026-08-19 feat(website): publish design v0.2.0
    [bom.csv, placements.csv, positions.csv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]
